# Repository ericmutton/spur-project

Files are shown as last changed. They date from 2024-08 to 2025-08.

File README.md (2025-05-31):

# spur-project

Musings in preparation for the 2025 [Summer Platform for Undergraduate Research](https://spur.utdallas.edu/).

# Getting Started

This repository contains the project files created during my Fall 2024 and Spring 2025 semesters.

## Hardware

The EDA schematic captures and prototype PC boards are maintained in separate KiCAD projects in the [Hardware](/Hardware) directory.
- Single-Cell PMIC and Switch-Mode PSU testbench
- NiceRF SA868 walkie-talkie module breakout board 

## Software

The source code utilizing either the Espressif Systems [ESP-IDF Arduino Core](https://github.com/espressif/arduino-esp32) (using FreeRTOS) for experimentation
or the Zephyr Standalone Application (using ZephyrRTOS) constituting the base radio platform firmware are both maintained in the [Software](/Software) directory.

# Scope

The scope of this research project is to build a two-way radio communications platform that remains extensible in arbitrary 'all-mode' FM modulation in both firmware and hardware.

This means adopting modern real-time operating system ecosystems, particularly the two RTOS under consideration are:
- [Zephyr Project](https://zephyrproject.org) [ZephyrRTOS](https://github.com/zephyrproject-rtos) (a Linux Foundation Project)
- [FreeRTOS](https://freertos.org/) (under Amazon AWS stewardship as of 2017)

For the hardware, the platform is to allow off-the-shelf (and few bespoke) integration of:
 - Wireless communications modules
   - [ ] GNSS/GPS receivers 
   - [ ] Sub-Ghz transceivers
   - [ ] LoRa transceivers
 - Peripheral Human-Machine Interface Devices (HIDs)
   - [ ] Potentiometers (Volume, Frequency), Keypad (DTMF, Navigation), Display
   - [ ] Mono CW Keyer, Keyboard, and USB devices
   - [ ] External audio source/sink, external modem/vocoder

## Groundwork

- [x] Develop a working 'two-way' radio prototype. 
  - [x] Phase out SA868 Demo Board by building a minimal breakout board
  - [x] Make prototype mobile through a rechargable cell and JEITA charger
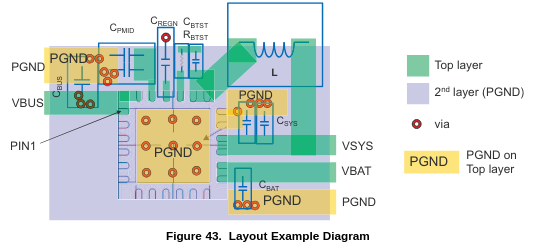
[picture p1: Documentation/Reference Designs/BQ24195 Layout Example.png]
BQ24195
    - 
  - [x] Amplify audio output of SA868 with anything other than an LM386 reference design
  - [x] Allow end-user to enter new RX and TX frequencies
  - [ ] All settings available to the end-user
  - [ ] Persistence of settings between power cycles

## Phase 1

For the purposes here, the SA868 is limited to arbitrary FM modes:
 - Analog FM Voice 
 - Amateur Packet Reporting System (APRS) 
 - Premodulated FM Waveforms

In Analog FM Voice, a parrot test or signal strength report (Readability-Strength-Tone) would be satisfactory.
## Phase 2
After verifying what can be done with the SA868, the next transceiver is the Texas Instruments CC1200. 

## Approach

A first-principles approach in designing this platform is to be taken on:
1. inter-device communications interfacing
   - [x] sensor device register-level configuration
   - [x] factory firmware flashing (see DMO module)
   - [x] microcontroller (a)synchronous peripheral utilization
2. utilizing vendor hardware abstractions
   - [x] device abstraction and tooling
     - [TI SimpleLink SDK](https://www.ti.com/tool/SIMPLELINK-LOWPOWER-SDK) >= v3.3
     - [SmartRF Studio](https://www.ti.com/tool/SMARTRFTM-STUDIO) == v7 (see TI CC1200)
   - [ ] subsystem abstraction
3. utilizing operating system abstractions
   - [ ] target hardware-application decoupling (see ZephyrRTOS)
   - [ ] communications stack normalization (see USB, IEEE 802.15.4, Bluetooth SIG)
   - [ ] tracing & debugging meta-tooling (see [openocd](https://openocd.org/))
4.  extensibility

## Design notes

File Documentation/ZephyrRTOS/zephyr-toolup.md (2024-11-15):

Goal
* Be able to run a driver sample as a [freestanding application](https://docs.zephyrproject.org/latest/develop/application/index.html#zephyr-freestanding-application)
* Run sample for Chargers API with [`ti,bq24190`](https://docs.zephyrproject.org/latest/build/dts/api/bindings/charger/ti,bq24190.html)on i2c `reg = <0x6B>;`

Preconditions
* Review page 17 of [BQ24195 datasheet](https://www.ti.com/lit/ds/symlink/bq24195.pdf)
* Battery charging is enabled by I2C register bit (`REG01[5:4]`) = 01 and CE is low

Methodology
For context, `zephyrproject/zephyr/samples/drivers/charger/src/main.c` has the following DeviceTree device node that needs to be set:
```c
static const struct device *chgdev = DEVICE_DT_GET(DT_NODELABEL(charger));
```

To make a Zephyr freestanding application, a proper zephyr repo instance is accessible but separate from an `app/` directory as shown below:
```md
<home>/
├─── zephyrproject/
│     ├─── .west/
│     │    └─── config
│     ├── zephyr/
│     ├── bootloader/
│     ├── modules/
│     └── ...
│
└─── app/
     ├── CMakeLists.txt
     ├── prj.conf
     ├── boards
         └── esp32c3_devkitm.overlay
     └── src/
         └── main.c
```

The contents of custom device tree overlay overriding `chgdev` for the `boards/esp32c3_devkitm.overlay` with app name `app` is shown below:
```c
&i2c0 {
	status = "okay";
	charger: bq24190@6b {
		compatible = "ti,bq24190";
		reg = <0x6B>; // I2C address of the BQ24195
		constant-charge-current-max-microamp = <2000000>;
		constant-charge-voltage-max-microvolt = <4200000>; 
	};
};
```

```c
cmake_minimum_required(VERSION 3.20.0)

set(BOARD esp32c3_devkitm)

find_package(Zephyr REQUIRED HINTS $ENV{ZEPHYR_BASE})

project(
	BMS-SMPS
	DESCRIPTION "Evaluation project for zephyr,charger API"
	LANGUAGES C
)

target_sources(
	app
	PRIVATE
	src/main.c
)
```

```conf
CONFIG_MAIN_STACK_SIZE=4096

# Enable console support
CONFIG_CONSOLE=y
CONFIG_UART_CONSOLE=y

# Enable GPIO support
CONFIG_GPIO=y

# Enable I2C for the ESP32-C3 Devkit
CONFIG_I2C=y
CONFIG_I2C_INIT_PRIORITY=60
  
# Enable the Charger API
CONFIG_CHARGER=y
# Set up the specific driver
CONFIG_CHARGER_BQ24190=y

# Enable logging (optional, for debugging)
CONFIG_LOG=y
CONFIG_TRACING_SYSCALL=y
CONFIG_LOG_DEFAULT_LEVEL=3
```

Postconditions
* Use an overlay file to set chgdev for using the `zephyr,charger` API sample.
* Put the BQ24193 into `CHARGER_STATUS_CHARGING` to charge an attached single 1.65 V 18650 cell and successfully run the `zephyr,charger` on an ESP32-C3 DEVKITM `--board esp32c3_devkitm`.
* Can run the following commands to build and flash:

```bash
# See https://github.com/zephyrproject-rtos/zephyr/pull/80342/
west init -m https://github.com/rriveramcrus/zephyr
west build
west flash
west espressif monitor
```

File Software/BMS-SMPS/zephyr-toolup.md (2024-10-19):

Goal
* Be able to run a driver sample as a [freestanding application](https://docs.zephyrproject.org/latest/develop/application/index.html#zephyr-freestanding-application)
* Run sample for Chargers API with [`ti,bq24190`](https://docs.zephyrproject.org/latest/build/dts/api/bindings/charger/ti,bq24190.html)on i2c `reg = <0x6B>;`

Preconditions
* Review page 17 of [BQ24193 datasheet](https://www.ti.com/lit/ds/symlink/bq24193.pdf)
* Battery charging is enabled by I2C register bit (`REG01[5:4]`) = 01 and CE is low

Methodology
For context, `zephyrproject/zephyr/samples/drivers/charger/src/main.c` has the following DeviceTree device node that needs to be set:
```c
static const struct device *chgdev = DEVICE_DT_GET(DT_NODELABEL(charger));
```

To make a Zephyr freestanding application, a proper zephyr repo instance is accessible but separate from an `app/` directory as shown below:
```md
<home>/
├─── zephyrproject/
│     ├─── .west/
│     │    └─── config
│     ├── zephyr/
│     ├── bootloader/
│     ├── modules/
│     └── ...
│
└─── BMS-SMPS/
     ├── CMakeLists.txt
     ├── prj.conf
     ├── boards
         └── esp32c3_devkitm.overlay
     └── src/
         └── main.c
```

The contents of custom device tree overlay overriding `chgdev` for the  `boards/esp32c3_devkitm.overlay` with app name `BMS-SMPS` is shown below:
```c
&i2c0 {
	status = "okay";
	charger: bq24190@6b {
		compatible = "ti,bq24190";
		reg = <0x6B>; // I2C address of the BQ24193
		constant-charge-current-max-microamp = <2000000>;
		constant-charge-voltage-max-microvolt = <4200000>; 
	};
};
```

```cmake
cmake_minimum_required(VERSION 3.20.0)

set(BOARD esp32c3_devkitm)

find_package(Zephyr REQUIRED HINTS $ENV{ZEPHYR_BASE})

project(
	BMS-SMPS
	DESCRIPTION "Evaluation project for zephyr,charger API"
	LANGUAGES C
)

target_sources(
	app
	PRIVATE
	src/main.c
)
```

```c
CONFIG_MAIN_STACK_SIZE=4096

# Enable console support
CONFIG_CONSOLE=y
CONFIG_UART_CONSOLE=y

# Enable GPIO support
CONFIG_GPIO=y

# Enable I2C for the ESP32-C3 Devkit
CONFIG_I2C=y
CONFIG_I2C_INIT_PRIORITY=60
  
# Enable the Charger API
CONFIG_CHARGER=y
# Set up the specific driver
CONFIG_CHARGER_BQ24190=y

# # Enable logging (optional, for debugging)
CONFIG_LOG=y
CONFIG_TRACING_SYSCALL=y
CONFIG_LOG_DEFAULT_LEVEL=3
```

Postconditions
* Use an overlay file to set chgdev for using the `zephyr,charger` API sample.
* Put the BQ24193 into `CHARGER_STATUS_CHARGING` to charge an attached single 1.65 V 18650 cell and successfully run the `zephyr,charger` on an ESP32-C3 DEVKITM `--board esp32c3_devkitm`.
* Can run the following commands to build and flash:
```bash
west build
west flash
west espressif monitor
```

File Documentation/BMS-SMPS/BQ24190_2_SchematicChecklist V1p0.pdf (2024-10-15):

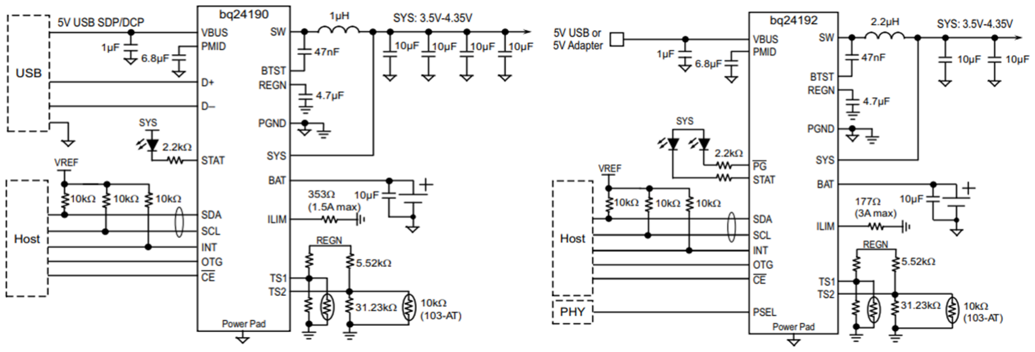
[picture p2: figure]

PIN NAME | REQUIREMENT | COMPONENT | MIN | TYP | MAX | DESCRIPTION | COMMENTS AND RELEVANT EQUATIONS
D+/D‐ BQ24190 ONLY | 2,3 | | USB data line pair
Optional | | | | | Positive line of the USB data line pair. | 1. D+/D‐ based USB host/charging port detection. The detection includes data contact detection(DCD), primary and secondary detection in BC1.2.
Optional | | | | | Negative line of the USB data line pair. | 2. If D+/D‐ based input current limit detection is not used, short D+/D‐ pins together.
PSEL BQ24192 ONLY | 2 | | Power source selection input.
Required | | | | | | High indicates a USB host source and Low indicates an adapter source. Do not float.
/PG BQ24192 ONLY | 3 | | Open drain active low power good indicator.
Optional | PG resistor | | 2.2 kΩ | 10 kΩ | Connect to the pull up rail via 10‐kΩ resistor. | LOW indicates a good input source if the input voltage is between UVLO and ACOV, above SLEEP mode threshold, and current limit is above 30 mA.
STAT | 4 | | Open drain charge status output
Optional | STAT resistor | | 2.2 kΩ | 10 kΩ | Connect to the pull up rail via 2.2‐kΩ resistor. | 1. If not used, leave it float. 2. HIGH indicates charge complete or charge disabled. When any fault Digital condition occurs, STAT pin in blinks at 1 Hz.
SCL/SDA | 5‐6 | | I2C Interface clock and data
Optional | SCL resistor | | 10 kΩ | | Connect SCL to the logic rail through a 10‐kΩ resistor. | If I2C communication is not used, leave it float.
Optional | SDA resistor | | 10 kΩ | | Connect SDA to the logic rail through a 10‐kΩ resistor. | If I2C communication is not used, leave it float.
INT | 7 | | Open‐drain Interrupt Output
Optional | INT resistor | | 10 kΩ | | Connect the INT to a logic rail via 10‐kΩ resistor. | 1. If not used, leave it float. 2. The INT pin sends active low, 256‐μs pulse to host to report charger device status and fault.
OTG | 8 | | Active high enable pin during boost mode.
Optional | | | | | USB current limit selection pin during buck mode, and active high enable pin during boost mode. | 1. If OTG boost mode is not used, short it to ground. 2. In buck mode with USB host (PSEL=High), when OTG = High, IIN limit = 500 mA and when OTG = Low, IIN Digital limit = 100 mA. 3. The boost mode is activated when the REG01[5:4] = 10 and OTG pin is High.
/CE | 9 | | Active low Charge Enable pin.
Required | | | | | | 1. /CE pin must be pulled High or Low. 2. Battery charging is enabled when REG01[5:4] = 01 and CE pin = Low.
ILIM | 10 | | Input current limit Input.
Required | ILIM resistor | | * Ω | | A resistor is connected from ILIM pin to ground to set the maximum limit as IINMAX = (1V/RILIM) × 530 | 1. The actual input current limit is the lower one set by ILIM and by I2C REG00[2:0]. 2.The minimum input current programmed on ILIM pin is 500 mA. 3. If ILIM pin is short, the input current limit is set by the register. 4. If ILIM pin is open, the input current is limited to zero
TS1, TS2 | 11,12 | | Temperature qualification voltage inputs.
Required | TS resistors and thermistor | | | | Connect a negative temperature coefficient thermistors. Recommend 103AT‐2 thermistors. | 1. If thermistor is not used, set TS pin voltage within normal range. 2. If thermistor is used, program temperature window with a resistor divider from REGN to TSx to GND. Charge suspends when either TS pin is out of range.
VBUS | 1,24 | | Input source to the charger
Required | VBUS caps | 1uF | | | | 1. Place a 1‐μF ceramic capacitor from VBUS to PGND and place it as close as possible to IC. 2. It is recommended to have a total of ~10uF capacitance at VBUS & PMID for USB input compliance.
PMID | 23 | | Actual input source to the charger
Required | PMID caps | 6.8uF | | | | Given the total input capacitance, put 1 μF on VBUS to PGND, and the rest capacitance on PMID to PGND.
VBAT | 13‐14 | | Positive battery connection point
Required | VBAT caps | 10uF | 10uF | | | 1. Connect a 10 μF closely to the BAT pin. 2. Charger may operate normally when battery is not connected.
VSYS | 15‐16 | | System connection point.
Required | VSYS caps | 20uF | 20uF | 40uF | | Connect a 20 μF closely to the SYS pin. The preferred ceramic capacitor is 6V or higher rating, X7R or X5R.
SW | 19‐20 | | Switching node connecting to output inductor.
Required | Output inductor | 1uH | | 2.2uH | | The charger device has internal loop compensator. To get good loop stability, the resonant frequency of the output inductor and output capacitor should be designed between 15 kHz and 25 kHz. With 2.2‐μH inductor, the typical output capacitor value is 20 μF.
| | Optional | SW Resistor | | * Ω | | Switching converter snubber circuit | Snubber circuit values empirically determined if required. Recommend unpopulated footprint on new designs.
| | Optional | SW Cap | | * F
BTST | 21 | | | | | | PWM high side driver positive supply.
| | Required | BTST‐SW cap | 0.047uF | 0.047uF | 0.047uF | | Connect the 0.047μF bootstrap capacitor from SW to BTST.
| | Optional | BTST resistor | | * Ω | | Bootstrap capacitor snubbing resistor | Help with EMI performance. Recommend unpopulated footprint on new designs.
REGN | 22 | | | | | | PWM low side driver positive supply output.
| | Required | REGN cap | 4.7uF | 4.7uF | 4.7uF | | Connect a 4.7 μF (10 Vrating) ceramic capacitor from REGN to analog GND. The capacitor should be placed close to the IC. REGN also serves as bias rail of TS1 and TS2 pins.
PGND | 17‐18 | | | | | | Power ground connection for high‐current power converter node.
| | Required | | | | | | On PCB layout, connect directly to ground connection of input and output capacitors of the charger. A single point connection is recommended between power PGND and the analog GND near the IC PGND pin.
PowerPAD | | Required | | | | | | Always solder PowerPAD Pad to the board, and have vias on the PowerPAD plane star‐connecting to PGND and ground plane for high‐current power converter.

## BQ24190/2 TYPICAL SCHEMATIC

## BQ24190/2 SCHMATIC CHECKLIST

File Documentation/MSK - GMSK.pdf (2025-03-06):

Appendix D – University of Hull | D1

### Appendix D – Digital Modulation and GMSK

A brief introduction to digital modulation schemes is given, showing the logical development of GMSK from simpler schemes. GMSK is of interest since it is used in the GSM system. The phase and amplitude relations between carrier cycles over a data bit are developed, enabling rigourous modelling of ensemble fields to be carried out.

D1. Phase shift keying

For binary PSK (BPSK)

S0(t) = A cos (ωt) | represents binary “0”
S1(t) = A cos (ωt + π) | represents binary “1”

For M-ary PSK, M different phases are required, and every n (where M=2n ) bits of the
binary bit stream are coded as one signal that is transmitted as
A sin (ωt + θj)
j=1,...,M.

D2. Quadrature Phase Shift Keying

If we define four signals, each with a phase shift differing by 90⁰
then we have
quadrature phase shift keying (QPSK).

The input binary bit stream {dk}, dk = 0,1,2,..... arrives at the modulator input at a rate 1/T bits/sec and is separated into two data streams dI (t) and dQ (t) containing odd and even bits respectively.
dI(t) = d0, d2, d4 ,...
dQ(t) = d1, d3, d5 , ...

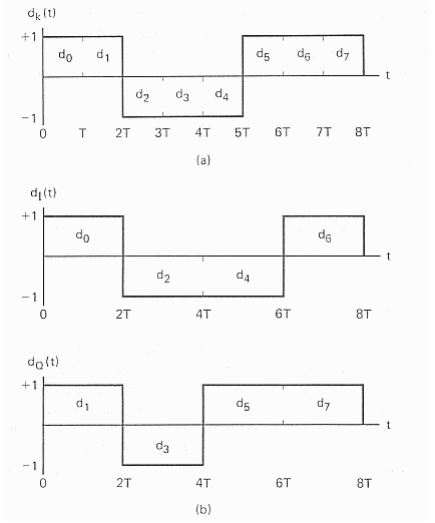
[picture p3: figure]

A convenient orthogonal realisation of a QPSK waveform , s(t) is achieved by amplitude modulating the in-phase and quadrature data
streams onto the cosine and sine functions of a carrier wave as follows:

s(t)=1/ 2 dI(t) cos (2πft + π/4) + 1/ 2 dQ(t) sin (2πft + π/4)

Using trigonometric identities this can also be written as

s(t)=A cos [2πft + π/4 + θ(t)].

The pulse stream dI(t) modulates the cosine function with an amplitude of ± 1. This is equivalent to shifting the phase of the cosine function by 0 or π; consequently this produces a BPSK waveform. Similarly the pulse stream dQ(t) modulates the sine function, yielding a BPSK waveform orthogonal to the cosine function. The summation of these two orthogonal waveforms is the QPSK waveform.

The values of θ(t) = 0, -(π/2), π/2, π represent the four possible combinations of aI (t) and aQ (t).

Each of the four possible phases of carriers represents two bits of data. Thus there are two bits per symbol. Since the symbol rate for QPSK is half the bit rate, twice as much data can be carried in the same amount of channel bandwidth as compared to BPSK. This is possible because the two signals I and Q are orthogonal to each other and can be transmitted without interfering with each other.

In QPSK the carrier phase can change only once every 2T secs. If from one T interval to the next one, neither bit stream changes sign, the carrier phase remains unchanged. If one component aI(t) or aQ (t) changes sign, a phase change of π/2 occurs. However if both components change sign then a phase shift of π occurs.

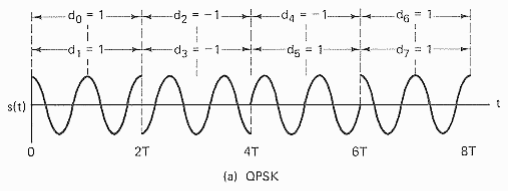
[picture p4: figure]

If a QPSK modulated signal undergoes filtering to reduce the spectral side lobes, the resulting waveform will no longer have a constant envelop and in fact, the occasional 180o
shifts in phase will cause the envelope to go to zero momentarily.

D3. Offset Quadrature Phase Shift Keying

If the two bit streams I and Q are offset by a 1/2 bit interval, then the amplitude fluctuations are minimised since the phase never changes by 180o
. This modulation
scheme, Offset Quadrature Phase shift Keying (OQPSK) is obtained from QPSK by delaying the odd bit stream by half a bit interval with respect to the even bit stream.

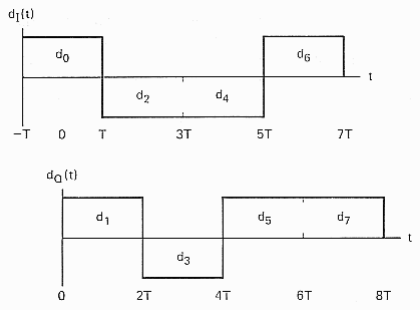
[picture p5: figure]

Thus the range of phase transitions is 0o

and 90o
(the possibility of a phase shift of 180o
is eliminated) and occurs twice as often, but with half the intensity of the QPSK. While amplitude fluctuations still occur in the transmitter and receiver they have smaller magnitude. The bit error rate for QPSK and OQPSK are the same as for BPSK.

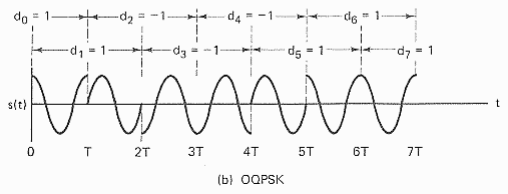
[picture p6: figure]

When an OQPSK signal undergoes bandlimiting, the resulting intersymbol interference causes the envelop to droop slightly to the region of ± 90o
phase transition, but since the phase transitions of 180 have been avoided in OQPSK, the envelop will never go to zero as it does in QPSK.

D4. Minimum Shift Keying

We previously showed that OQPSK is obtained from QPSK by delaying the Q data stream by 1 bit or T seconds with respect to the I data stream. This delay has no effect on the error or bandwidth.

Minimum Shift Keying (MSK) is derived from OQPSK by replacing the rectangular pulse in amplitude with a half-cycle sinusoidal pulse. The MSK signal is defined as:

S(t) = d(t) cos (πt/2T) cos 2πft + d(t) sin (πt/2T) sin 2πft.

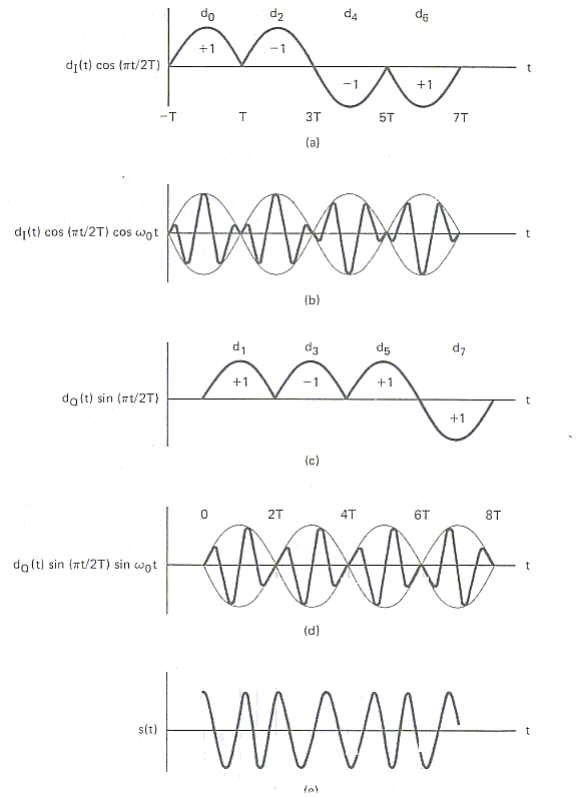
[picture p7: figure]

The MSK modulation makes the phase change linear and limited to ± (π/2) over a bit interval T. This enables MSK to provide a significant improvement over QPSK. Because of the effect of the linear phase change, the power spectral density has low side lobes that help to control adjacent-channel interference. However the main lobe becomes wider than the quadrature shift keying.

D5. Gausssian Minimum Shift Keying (GMSK)

In MSK we replace the rectangular pulse with a sinusoidal pulse. Obviously other pulse shapes are possible. A Gaussian-shaped impulse response filter generates a signal with low side lobes and narrower main lobe than the rectangular pulse. Since the filter theoretically has output before input, it can only be approximated by a delayed and shaped impulse response that has a Gaussian - like shape. This modulation is called Gaussian Minimum Shift Keying (GMSK).

The relationship between the premodulation filter bandwidth, B and the bit period, T defines the bandwidth of the system. GSM designers used a BT = 0.3 with a channel data rate of 270.8 kbs. This compromises between a bit error rate and an out-of-band interference since the narrow filter increases the intersymbol interference and reduces the signal power.

D5.1 GMSK Modulation
There are two methods to generate GMSK, one is frequency shift keyed modulation, the other is quadrature phase shift keyed modulation.

GMSK implemented by Frequency Shift Keying modulation with FM-VCO.

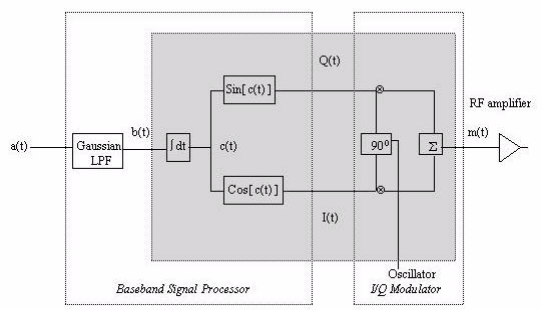
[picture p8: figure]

GMSK implemented by a quadrature baseband method.

The shaded areas in the two above figures have the same function.

The GMSK VCO-modulator architecture as shown in the first is simple but is not however, suitable for coherent demodulation due to component tolerance problems. This method requires that the frequency deviation factor of the VCO exactly equals 0.5, but the modulation index of conventional VCO based transmitters drifts over time and temperature.

a(t)

m(t) | RF Amplifier Gaussian
LPF

VCO
m=0.5

The implementation in the second employs a quadrature baseband process followed by a quadrature modulator. With this implementation, the modulation index can be maintained at exactly 0.5. This method is also cheaper to implement.

Both methods lead to the same GMSK modulated signal.

We are going to be looking at the second of these two methods, that is we shall be looking at a quadrature baseband processor followed by a quadrature modulator as shown in the second.

The Gaussian low-pass filter has an impulse response given by the following equation

g(t) = 1
2T [Q(2πBb

t − T /
ln

2
2 )-Q(2πBb

t + T /
ln

2
2 )]

for

0≤ Bb T ≤ ∞
where Q(t) is the Q-function

Q(t) = 1
2 t

∫ exp (-x²
/2) dx ,

Bb is the bandwidth of the low pass filter having a Gaussian shaped spectrum, T is the bit period and BN=Bb T is the normalised bandwidth.

To demonstrate this, we are looking at a filter with a bandwidth of Bb =1000 and a bit rate of T=1/2000, i.e. a normalised bandwidth BN=Bb.T =0.5.

The impulse response of the Gaussian low-pass filter has to be truncated and scaled, according to the BN value, to ensure that the effect of a single 1 passing through the filter, is a phases change of π/2.

For a BN of 0.5 the filter response is truncated, symmetrically around zero, to two bit periods, i.e. from -T to T. The truncated filter response is represented graphically in the following figure.

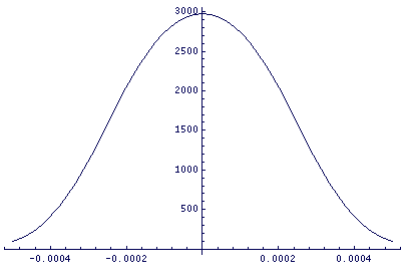
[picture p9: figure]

Ensuring that the response of the filter to a single 1 is a phase change of π/2, is equivalent to choosing the constant K to satisfy the following equation

Kg t dt

T

T
( ) =

−

∫ | π/2.

To demonstrate the modulation, we are using the following randomly chosen binary data stream. (This data stream repeats after 12 bits.)

{1,1,-1,1,1,-1,-1,1,-1,1,-1,-1, 1,1,-1,1,1,-1,-1,1,-1,1,-1,-1, | }.

The beginning of this data stream can be represented graphically by the following

The truncated and scaled impulse response of the Gaussian low-pass filter.

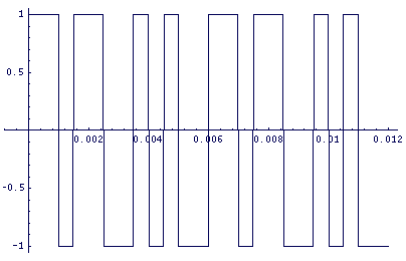
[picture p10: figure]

The beginning of the data stream being sent through the filter.

As the data passes through the filter it is shaped and ISI (inter symbol interference) is introduced since more than one bit is passing through the filter at any one time. For BN = 0.5, since the bits are spread over two bit periods, the second bit enters the filter as the first is half way through, the third enters as the first leaves etc....

The first few Gaussian shaped pulses are represented graphically in the following figure.

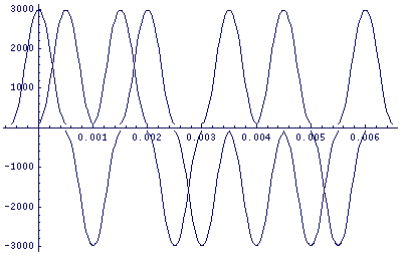
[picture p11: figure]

These individual shaped pulses are then added together to give a function which is represented graphically in the following figure. This is the function denoted by b(t).

The individual shaped pulses representing the data stream.

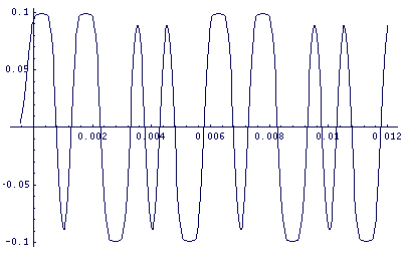
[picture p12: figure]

The function b(t) as in the second figure

This function, b(t), is then integrated, with respect to t (time) from t to ∞, to give the function c(t) as shown in the second figure. This function c(t) is represented graphically below.

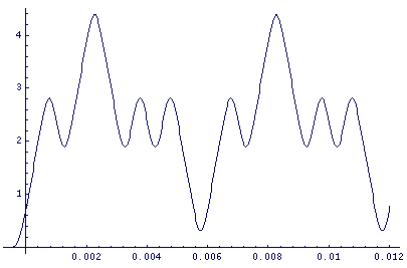
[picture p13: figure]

Once we have the function c(t), we take Sine and Cosine functions of it to produce the I and Q-baseband signals. Taking the Cosine of c(t) produces the I-baseband signal I(t) i.e.

I(t) = Cos[ c(t) ].

This function I(t) is represented graphically below.

The function c(t) as in the second figure.

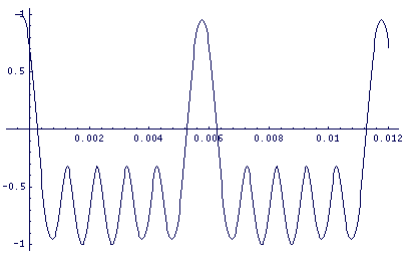
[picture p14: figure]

The I-baseband signal, i.e. the function I(t) as the second figure

Taking the Sine of c(t) produces the Q-baseband signal Q(t) i.e.

Q(t) = Sin[ c(t) ].

This function Q(t) is represented graphically below.

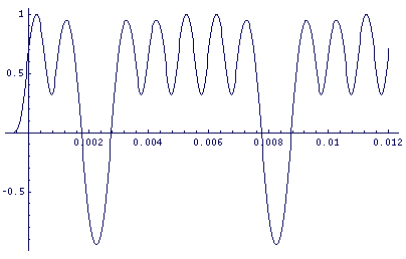
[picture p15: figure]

These two functions I(t) and Q(t) are then passed through the I/Q modulator which leads to the output signal m(t) which can be written as

m(t) = Sin(2πfc t) I(t) + Cos(2πfct) Q(t),

where fc is the carrier frequency used as the oscillator in the second figure

The GMSK signal m(t) is represented

The Q-baseband signal, i.e. the function Q(t) as in the second figure.

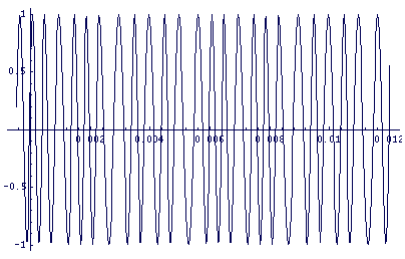
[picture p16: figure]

The GMSK modulated signal m(t) as in the second figure.

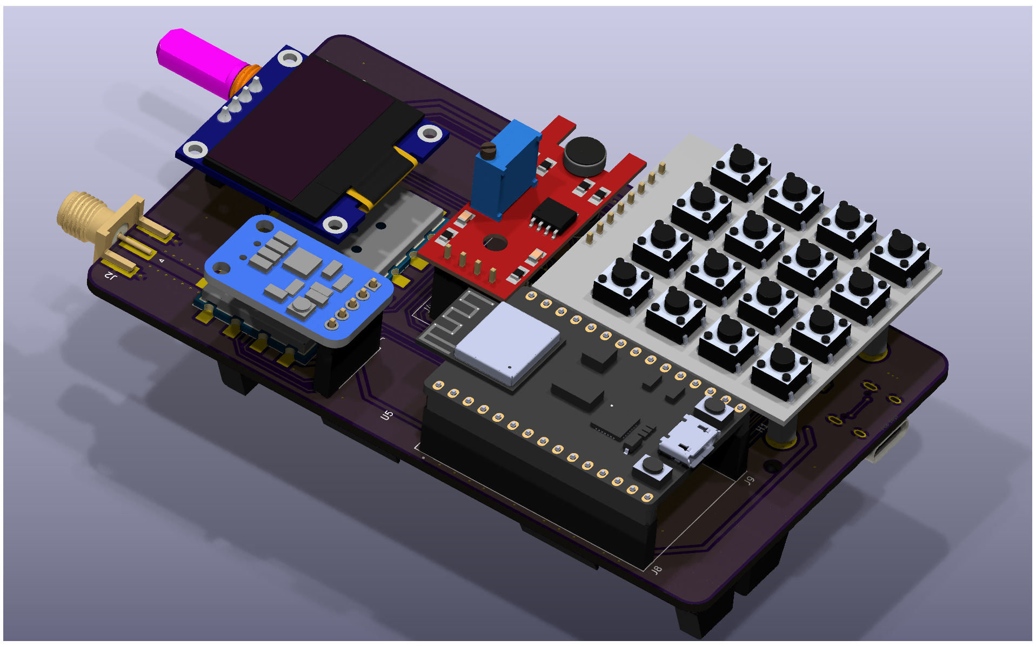
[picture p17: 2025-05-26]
Hardware/KiCAD/spur-demo/spur-demo.png

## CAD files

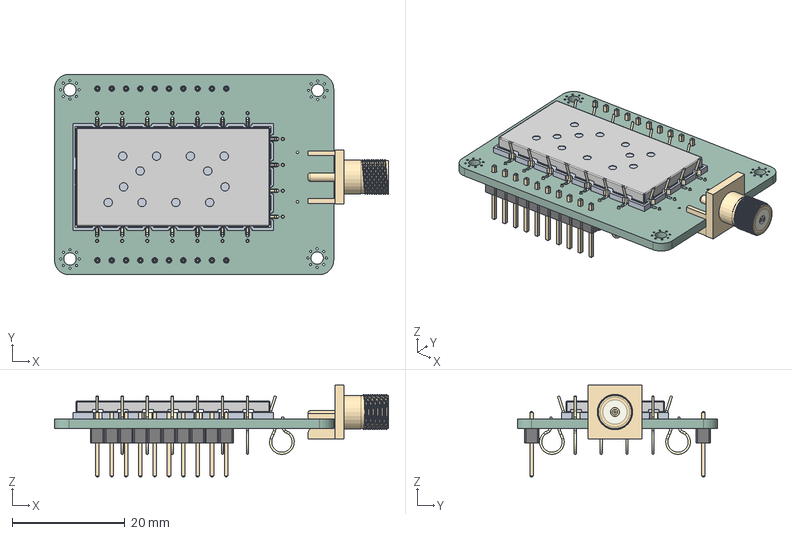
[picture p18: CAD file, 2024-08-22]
Hardware/KiCAD/sa8x8-breakout/sa8x8-breakout.step
59.3 x 35.6 x 16.2 mm
(Unsaved) x 18
SMA_Molex_73251-1153_EdgeMount_Horizontal
SA818 v44
PinHeader_1x10_P254mm_Vertical x 2
sa8x8-breakout_PCB

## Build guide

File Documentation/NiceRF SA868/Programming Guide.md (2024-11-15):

# Programming Guide

##  Flashing the SA868 RF Module

If using the SA868 OpenEdition, it is necessary to flash a firmware onto the onboard Renesas RL78 microcontroller. The requisite programming interface is exposed on the module as shown below.

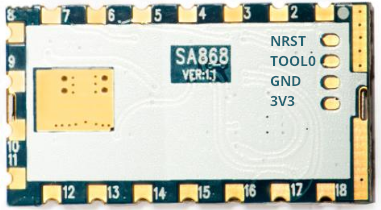
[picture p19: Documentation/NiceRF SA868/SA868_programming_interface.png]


> [!IMPORTANT] 
> The [rl78flash](https://github.com/msalau/rl78flash) command line serial programmer is required for these steps.

To flash the module, mode 3 is specified for the serial bootloader. a USB-TTY serial programming cable must then be fashioned to reflect the requisite hardware as shown below.

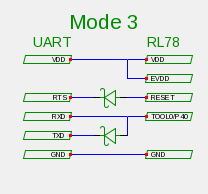
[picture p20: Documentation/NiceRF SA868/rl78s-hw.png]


```bash
rl78flash -m 3 -a -v /dev/ttyUSB0 sa868s-v1.0-patched.s37
```

## Communicating with the SA868

### Factory SA868 communication protocol

#### UART Interface Configuration
* Baud rate = 9600 Baud
* Data bit = 8 bit
* Parity = None
* Stop bit = 1 bit
* Logic Levels = 0 V, 3.3 V

#### Instruction Transmission Format

* `AT+DMOCONNECT`
* `S+sweep_freq`
    - `[134:174]`.[mod 1250]: valid VHF frequency when BW = `0`
    - `[400:480]`.[mod 2500]: valid UHF frequency when BW = `1`
* `AT+DMOSETGROUP=bandwidth_wide_fm,tx_freq,rx_freq,tx_subaudio,squelch,rx_subaudio`
    - bandwidth_wide_fm `[0:1]`: `0` = 12.5kHz or `1` = 25kHz
    - tx_freq, rx_freq
        - `[134:174].[mod 1250]`: valid VHF frequency when BW = `0`
        - `[400:480].[mod 2500]`: valid UHF frequency when BW = `1`
    - tx_subaudio, rx_subaudio
        - `0000`: subaudio disabled 
        - `[0001:0038]`: CTCSS
        - `[023?:754?]`: CDCSS code (?=N indicates complement or ?=I)
    - squelch `[0:8]`: `0` = listen mode or `[1:8]` squelch
* `AT+DMOSETVOLUME=volume_level`
    - `[1:8]`: set configured volume level to X
* `AT+RSSI?`
* `AT+SETFILTER=emphasis,voice_highpass,voice_lowpass`
    - `0`: emphasis,voice_highpass,voice_lowpass normal
    - `1`: emphasis,voice_highpass,voice_lowpass bypass

#### Instruction Return Format:

* `+DMOCONNECT:0` -> Normal working status
* `S=X`
  - `S=0` -> The frequency to be scanned has a signal
  - `S=1` -> There is no signal to sweep the frequency
* `+DMOSETGROUP=X`
  - `+DMOSETGROUP:0` -> Successfully set working parameters
  - `+DMOSETGROUP:1` -> Data setting is out of range
* `DMOSETVOLUME=X`
  - `+DMOSETVOLUME:0` -> Successfully set volume level
  - `+DMOSETVOLUME:1` -> Failed volume level setup
* `RSSI:XXX` -> Current signal strength value from 0 to 255, unit 1dB
* `+DMOSETFILTER:X`
  - `+DMOSETFILTER:0` -> Successfully set module filter
  - `+DMOSETFILTER:1` -> Failed filter setup

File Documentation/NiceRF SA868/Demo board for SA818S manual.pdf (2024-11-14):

# SA818 MANUAL

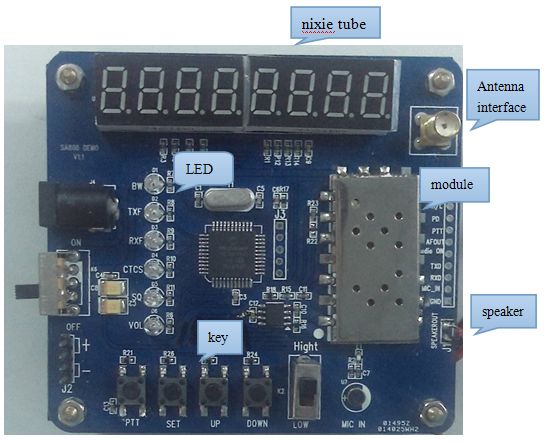
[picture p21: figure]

Key operation:
1 key SET
Press it to setting mode, the data on LED nixie tube will be flickering, you can change it by key UP or DOWN; Press key SET again, the item flickering will shift. If the item flickering is the last one, it will quit setting mode.

2 key UP
When in setting mode, pressing key UP will increase the flickering value.

3 key DOWN
When in setting mode, pressing key DOWN will decrease the flickering value. Otherwise it will move down the light LED.

4 key PTT
Pressing it will make the module into sending mode, when loosen the module into receiving mode.

5 Dial switch
When sending mode, switch to HIGH will send with high power, switch to LOW will send with low power.

Set TX frequency
After power on, the LED close to “TXF” is on, indicates that LED nixie tube is displaying TX frequency. Press key SET, the highest order of frequency will flicker, and can be changed by key UP or

DOWN. Press key SET to set the next order.

Set bandwidth
Press key DOWN, the LED close to “BW” is on, indicates that LED nixie tube is displaying bandwidth, pressing key SET to setting mode and press key DOWN to change bandwidth.

Set RX subaudio.
Press key DOWN, the two LEDS close to “RXF” and “CTCS” are light up, it indicates that LED nixie tube is displaying receiving subaudio. Press key SET to change receiving subaudio. If the LED nixie tube display “00”, it means that no subaudio in receiving mode. If display “tcs”, it means that receiving subaudio is analog, and if display “cds”, it means that receiving subaudio is digital.

Set volume
Press key DOWN, the LED close to “VOL” is on, press key SET to setting mode, and can be changed by key UP or DOWN.

Set SQ
Press key DOWN, the LED close to “SQ” is on, press key SET to setting mode, and can be changed by key UP or DOWN.

Set TX subaudio.
Press key DOWN, the two LEDS close “TXF” and “CTCS” are on, indicates that LED nixie tube is displaying sending subaudio. Press key SET to change sending subaudio. If the LED nixie tube display “00”, it means that no subaudio in sending mode. If display “tcs”, it means that sending subaudio is analog, and if display “cds”, it means that sending subaudio is digital.

Set RX frequency
Press key DOWN, the LED close to “RXF” is on, indicates that LED nixie tube is displaying RX frequency. Press key SET, the highest order of frequency will flickering, and can be changed by key UP or DOWN.

Press key SET to set the next order.
Press key UP, it will start to scan frequency and subaudio, the frequency displayed on the LED nixie tube will increase quickly and check the module whether receive the frequency and the subaudio, it will stop when there is any signal or press key DOWN.

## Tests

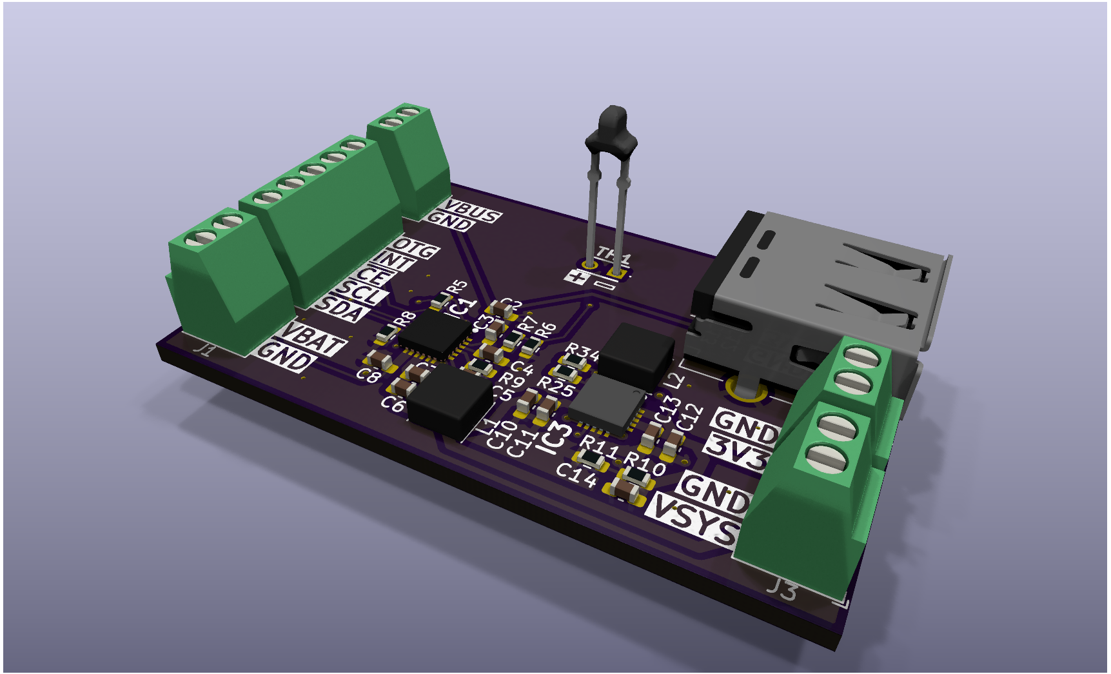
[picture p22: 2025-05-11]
Hardware/KiCAD/bms-smps-testbench/image.png

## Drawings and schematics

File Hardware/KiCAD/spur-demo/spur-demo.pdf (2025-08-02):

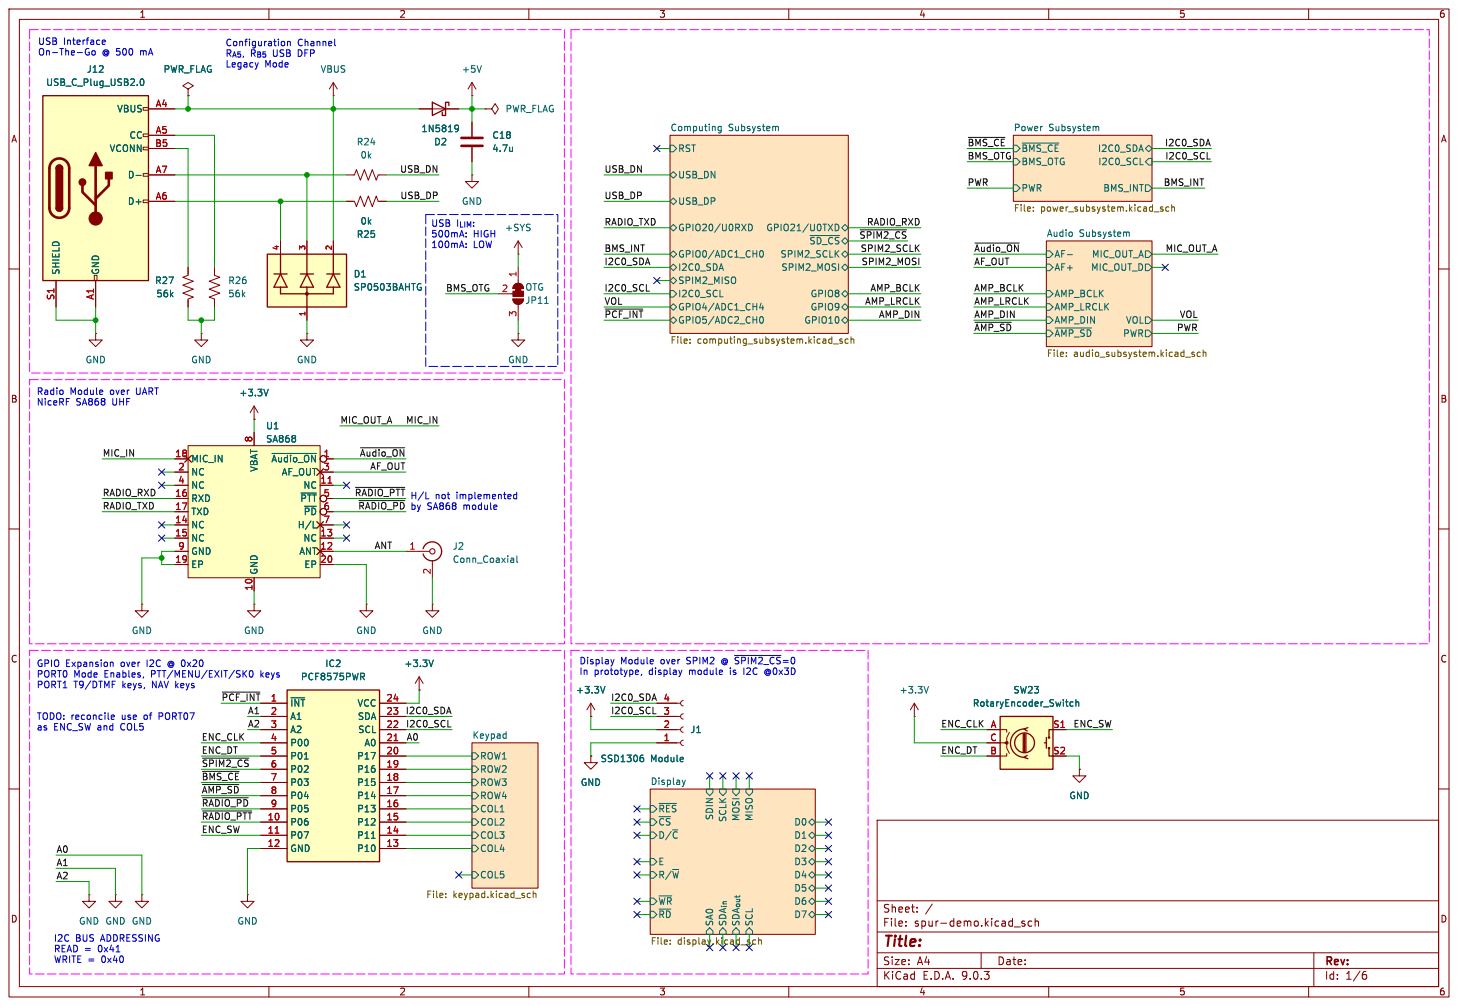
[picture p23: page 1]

Id: 1/6 Title: File: spur-demo.kicad_sch Sheet: /

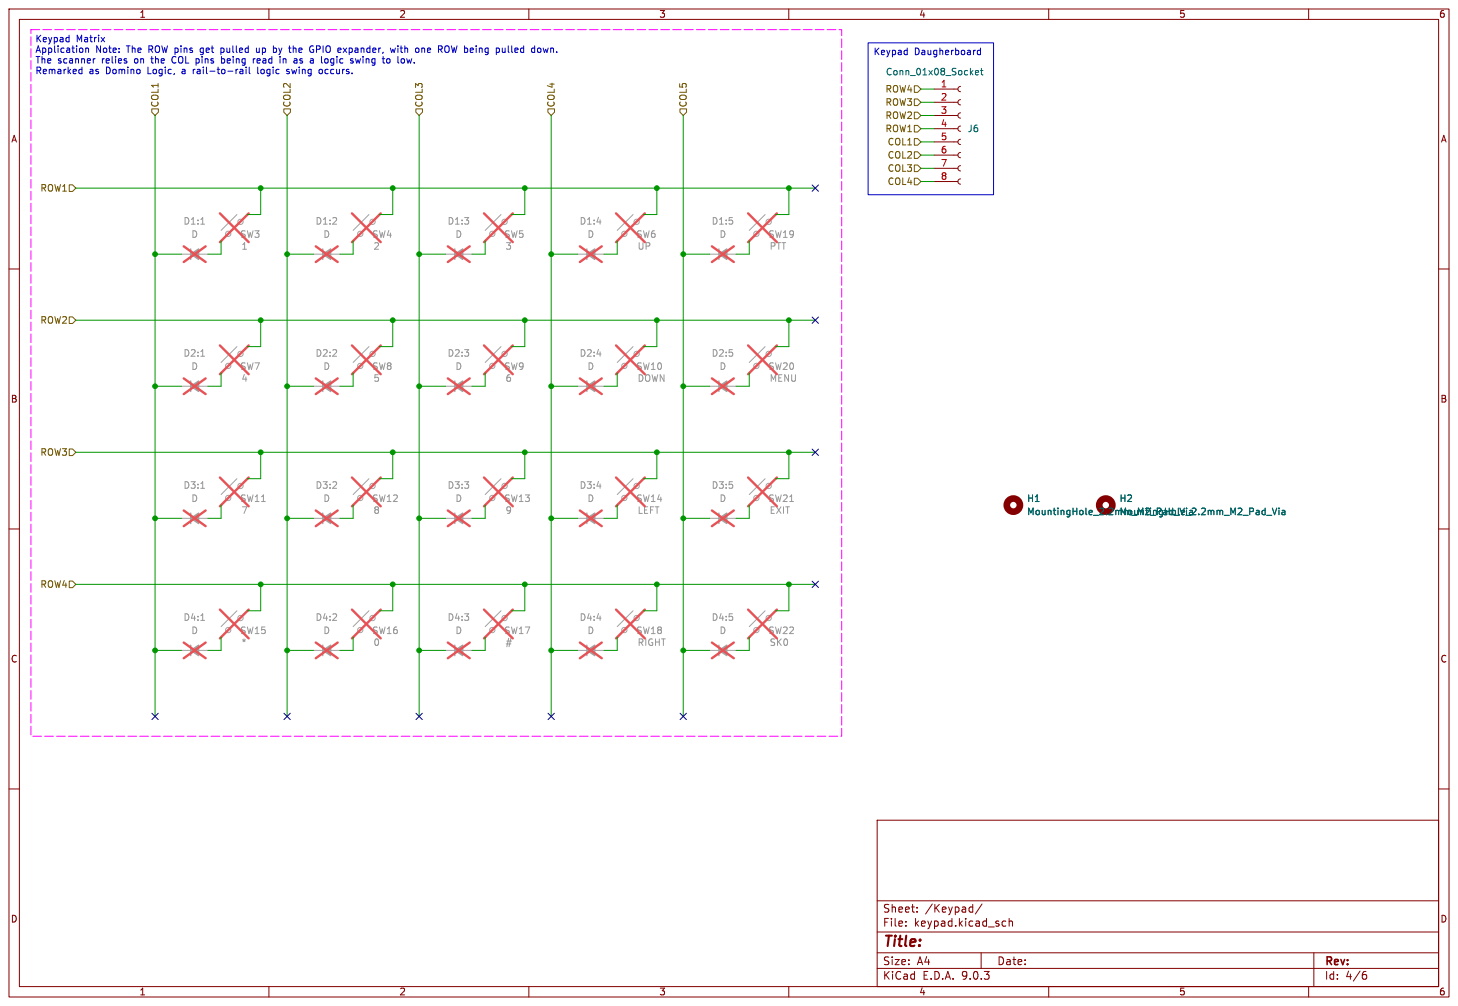
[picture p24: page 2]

Id: 4/6 Title: File: keypad.kicad_sch Sheet: /Keypad/

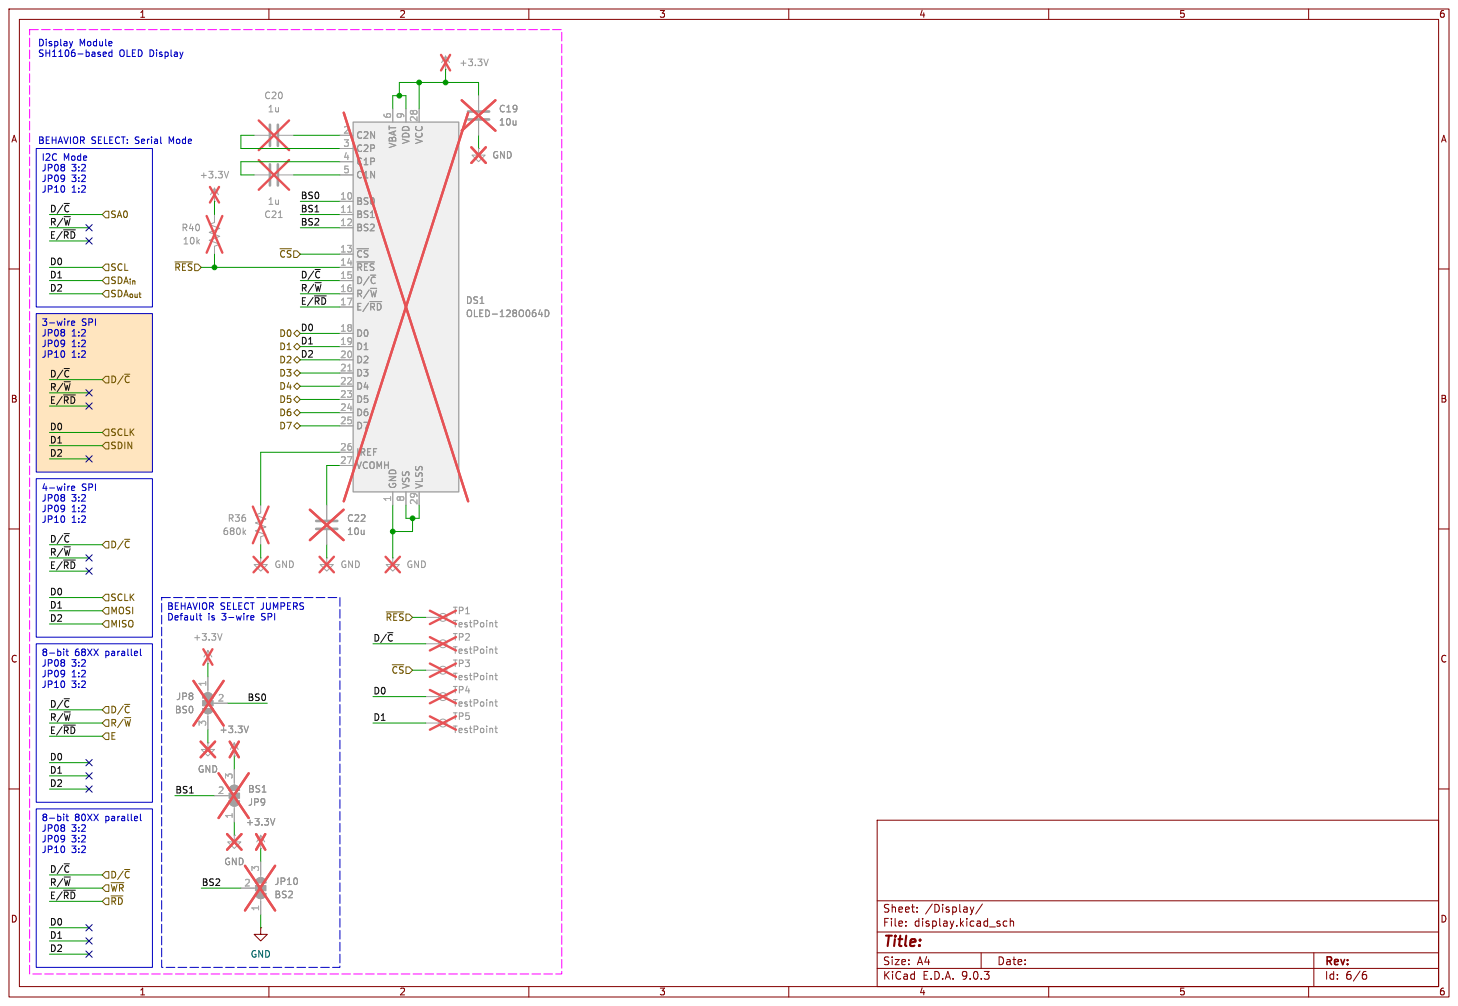
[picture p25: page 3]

Id: 6/6 Title: File: display.kicad_sch Sheet: /Display/

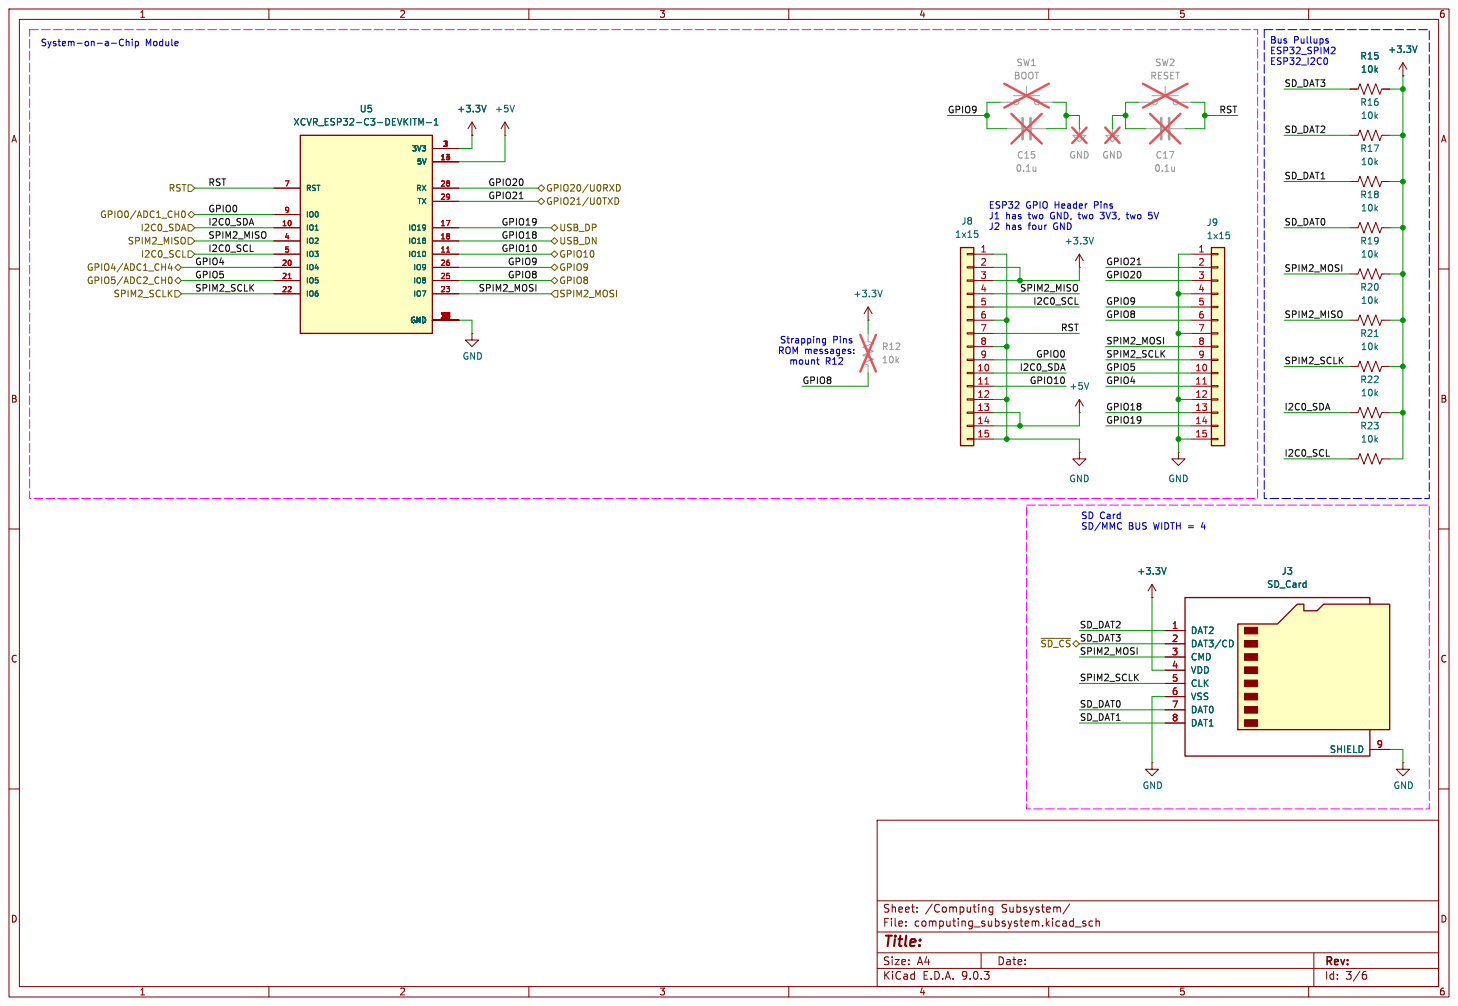
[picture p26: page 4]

J1 has two GND, two 3V3, two 5V
J2 has four GND

SD Card SD/MMC BUS WIDTH = 4

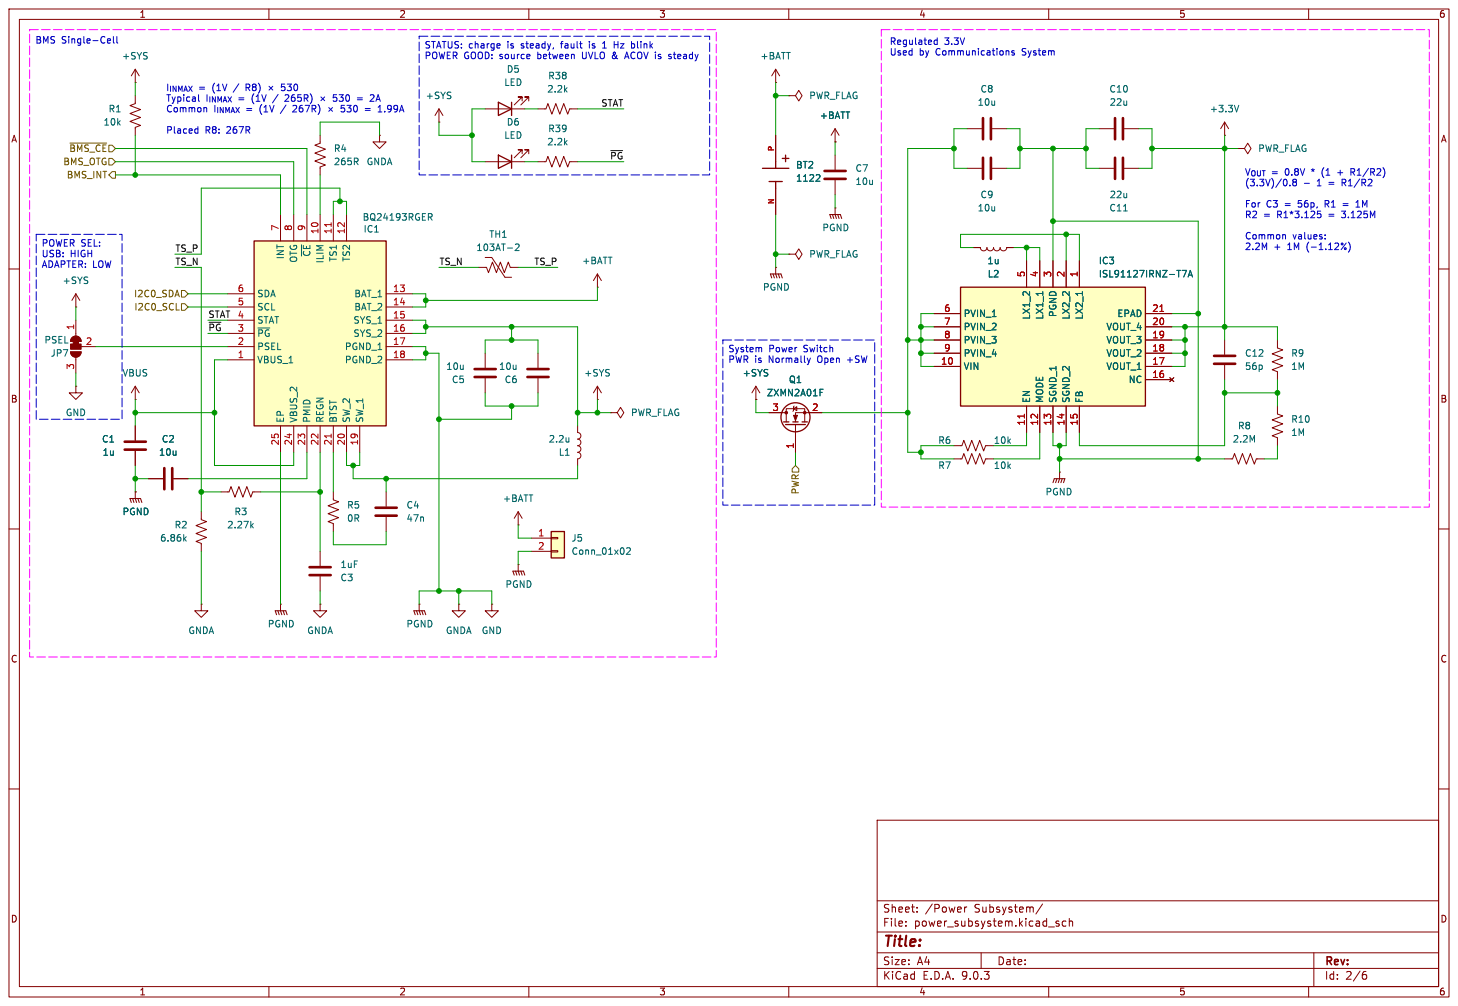
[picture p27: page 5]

STATUS: charge is steady, fault is 1 Hz blink POWER GOOD: source between UVLO & ACOV is steady
LED

I_{INMAX} = (1V / R8) þÿ×530 Typical I_{INMAX} = (1V / 265R) þÿ×530 = 2A Common I_{INMAX} = (1V / 267R) þÿ×530 = 1.99A

5 EPAD 21 PVIN_1 6 VOUT_4 20 PVIN_2 7 VOUT_3 19 PVIN_3 8 VOUT_2 18 PVIN_4 9 VOUT_1 17 VIN 10 NC 16 FB 15 SGND_2 14 SGND_1 13 MODE 12 EN 11 BT2
1122PWR_FLAG

8 PMID 23 ~{CE} 9 REGN 22 ILIM 10 BTST 21 TS1 11 SW_2 20 TS2 12 SW_1 19 PGND_2 18 PGND_1 17 SYS_2 16 SYS_1 15 BAT_2 14 BAT_1 13

POWER SEL: USB: HIGH
+SYS GND

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

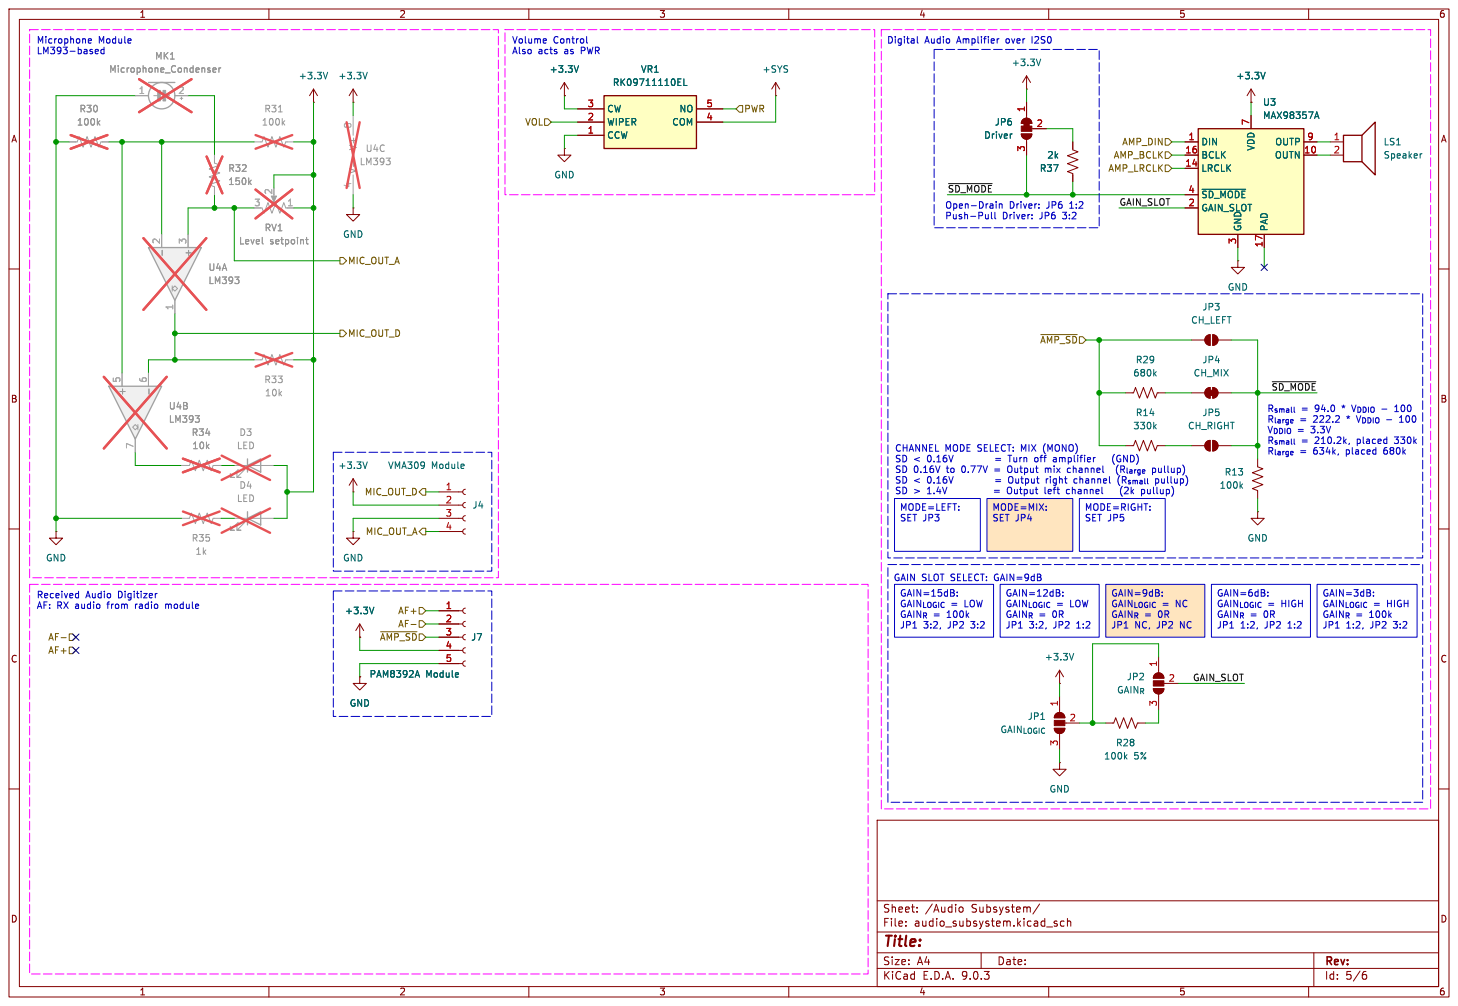
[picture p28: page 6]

R_{small}= 94.0 * V_{DDIO} - 100 R_{large}= 222.2 * V_{DDIO} - 100 V_{DDIO} = 3.3V R_{small}= 210.2k, placed 330k R_{large}= 634k, placed 680k R30

JP1 1:2, JP2 1:2 MODE=MIX: SET JP4 GAIN=12dB: GAIN_{LOGIC} = LOW

JP1 1:2, JP2 3:2 MODE=RIGHT: SET JP5 GAIN=9dB: GAIN_{LOGIC} = NC GAIN_{R}= 0R

Received Audio Digitizer AF: RX audio from radio module

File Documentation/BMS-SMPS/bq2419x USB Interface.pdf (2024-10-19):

# bq24190 Interface to USB

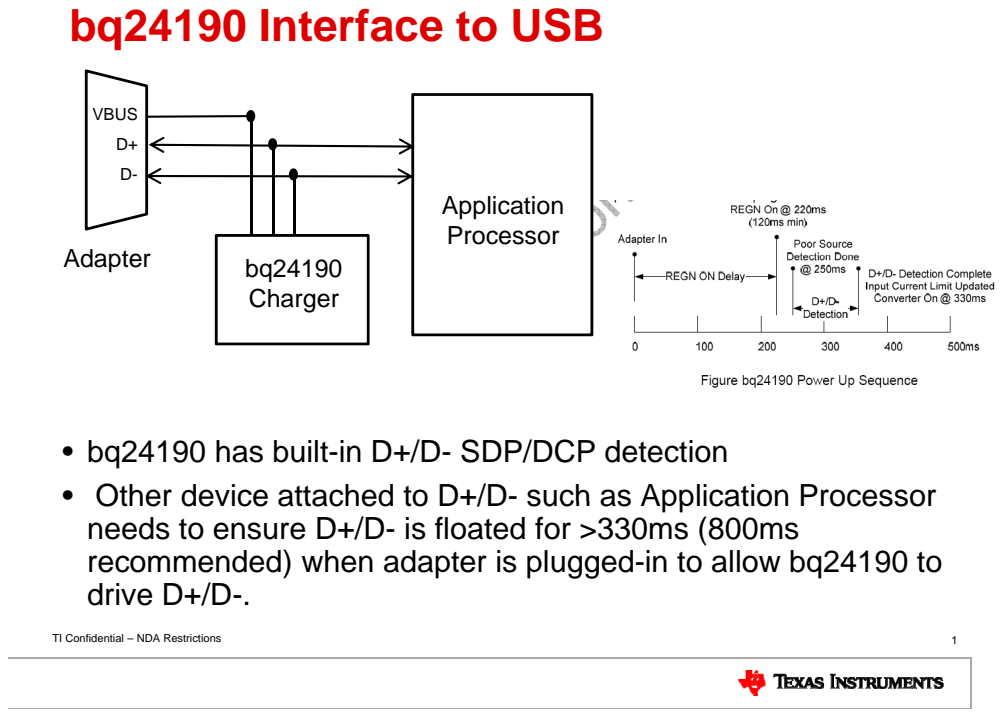
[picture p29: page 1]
VBUS; Application Processor; bq24190 Adapter Charge; TI Confidential – NDA Restrictions

• bq24190 has built-in D+/D- SDP/DCP detection
• Other device attached to D+/D
needs to ensure D+/D- is floated for >330ms (800ms
recommended) when adapter is plugged-in to allow bq24190 to
drive D+/D-.

- such as Application Processor

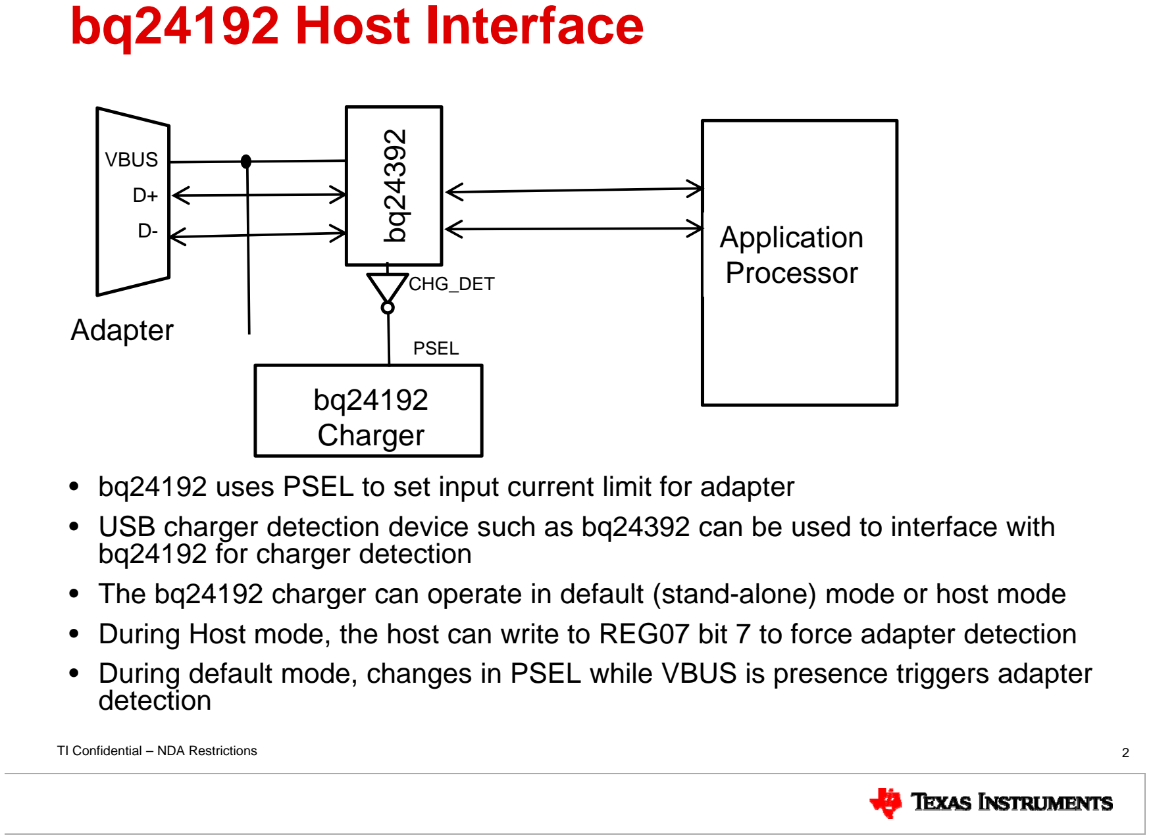
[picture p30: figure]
bq24192 Host Interface; VBUS; Application Processor; Adapter; CHG_DET; bq24192 Charger; PSEL; bq24192 for charger detection; detection; TI Confidential – NDA Restrictions

- bq24192 uses PSEL to set input current limit for adapter
- USB charger detection device such as bq24392 can be used to interface with
- The bq24192 charger can operate in default (stand- alone) mode or host mode
- During Host mode, the host can write to REG07 bit 7 to force adapter detection
- During default mode, changes in PSEL while VBUS is presence triggers adapter

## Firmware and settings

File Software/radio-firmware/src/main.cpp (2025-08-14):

#include "bq24190.h"
#include "pcf8575.h"
#include "pam8302a.h"
#include "sa868.h"
#include "ssd1306.h"

#define DEBUG_KEYPAD Serial
#define DEBUG_RSSI Serial

#define TASK_STACK_SIZE (4096)

#define SDA_PIN (1)
#define SCL_PIN (3)

#define PCF8575_INT_PIN (5)
pcf8575_config_t pcf8575;
#define ENCODER_CLK_PIN (PORT00)
#define ENCODER_DT_PIN (PORT01)
#define ENCODER_SW_PIN (PORT07)

#define PTT_BUTTON_PIN (PORT06) 


#define MAX_DISPLAY_COUNT 128
char display_buffer[MAX_DISPLAY_COUNT];
char *display_format_buffer;
ssd1306_config_t ssd1306;
TimerHandle_t displayTimer;

/* BQ24190 definitions */
#define BQ24190_INT_PIN (0)
// #define BQ24190_OTG_PIN
#define BQ24190_NCE_PIN (PORT03)
bq24190_config_t bq24190;
TimerHandle_t powerTimer;

// Table 16. REG09 Fault Register Description
const char* charger_faults_tag[4] {
  "Normal, ",
  "Input Fault (VBUS OVP or VBAT < VBUS < 3.8 V), ",
  "Thermal shutdown, ",
  "Charge Safety Timer Expiration, "
};
const char* ntc_faults_tag[5] {
  "Normal (T2-T3), ",
  "Warm (T3-T5), ",
  "Cool (T1-T2), ",
  "Cold (< T1), ",
  "Hot (> T5), "
};

int key_ghost_count;
int keys_entered;
int short_press_delay_milliseconds = 250;
int long_press_delay_milliseconds = 500;
TimerHandle_t inputTimer;

/* MAX98357A definitions */
// #define MAX98357A_BCLK (8)
// #define MAX98357A_LRCLK (9)
// #define MAX98357A_DIN (2)
// #define MAX98357A_SD (PORT04)
// max98357a_config_t max98357a;

#define PAM8302A_SD (PORT04)
pam8302a_config_t pam8302a;

/* SA868 definitions */
#define BAUD_RATE (9600)
#define RX_PIN (20)
#define TX_PIN (21)
#define SA868_PD_PIN (PORT05)
sa868_config_t sa868;
TimerHandle_t pttTimer;

volatile bool inputFlag = false;
void inputISR() {
  inputFlag = true;
}
// Rotary Encoder Increment Handling
volatile int rotary_encoder_clock = 0;
volatile int rotary_encoder_clocked = 0;
int rotary_encoder_counter = 0;
bool rotary_encoder_direction = false;
bool rotary_encoder_pressed = false;
bool rotary_encoder_ccw = false;
// Quadrature Encoding
void readEncoderDirection() {
  rotary_encoder_clock = pcf8575_readPort(ENCODER_CLK_PIN);
  if (rotary_encoder_clock != rotary_encoder_clocked
    && rotary_encoder_clock == 1) {
      if (pcf8575_readPort(ENCODER_DT_PIN) != rotary_encoder_clock) {
        rotary_encoder_counter--;
        rotary_encoder_ccw = true;
      } else {
        rotary_encoder_counter++;
        rotary_encoder_ccw = false;
      }
      Serial.printf("Rotary Encoder Incremented to (%d) %s\n",
        rotary_encoder_counter,
        rotary_encoder_ccw ? "CW" : "CCW");
  }
  rotary_encoder_clocked = rotary_encoder_clock;
}

// Push-To-Talk Button Handling
volatile bool ptt = false;
int pttElapsedSeconds = 0; // Elapsed PTT time in seconds
int pttTimeoutSeconds = 0; // Previous PTT time in seconds
// Software timer callback for counting PTT time in seconds 
void pttTimeoutCallback(TimerHandle_t xTimer) {
  pttElapsedSeconds++;
}
void activePTT() {
  pttTimeoutSeconds = pttElapsedSeconds;
  // Push-to-Talk has an optional timeout.
  if (sa868.PTT_TIMEOUT_SECONDS != -1 && pttTimeoutSeconds >= sa868.PTT_TIMEOUT_SECONDS) {
    //pcf8575_writePort(SA868_PTT_PIN, HIGH);  // Bypass PTT
    xTimerStop(pttTimer, 0);
    ptt = false;
    Serial.println("PTT Timeout reached, bypassing PTT...");
  }
}

// Potentiometer wiper is on ADC input pin.
#define VOLUME_WIPER_PIN 4

// const int frequency = 440; // frequency of square wave in Hz
// const int amplitude = 500; // amplitude of square wave
// const int sampleRate = 8000; // sample rate in Hz
// const int bps = 16;

// const int halfWavelength = (sampleRate / frequency); // half wavelength of square wave

// short sample = amplitude; // current sample value
// int count = 0;

//i2s_mode_t mode = I2S_PHILIPS_MODE; // I2S decoder is needed


void loop() {
  // Empty. Things are done in Tasks.
}

/*--------------------------------------------------*/
/*---------------------- Tasks ---------------------*/
/*--------------------------------------------------*/

// Received Signal Strength Indicator Handling
void updateRSSI() {
  int val = DMOERROR;
  // val = sa868_communication_handler(RSSI);
  if (val != DMOERROR) {
    // Datasheet suggests the module reports RSSI in dB.
    // What is the fixed reference value for the SA868?
    val += sa868.rssi_offset; // calibration offset for dBm
    //val *= -1; // RSSI is expected to be sub-milliwatt
    // -73 dBm is S9, -174 dBm S0
    sa868.rssi = -1*(255 - val);
    if (sa868.rssi != val) {
      sa868.rssi = val;
    }
  }
}

// Keypad Handling
char entry[8] = "";
bool rx_entry_mode = false, tx_entry_mode = false;

// TODO: make an alarm that indicates short or long keypresses.
void readKeypadEntry(char key) {
  if (key != '\0') {
    char key_to_enter[2];
    key_to_enter[0] = key;
    key_to_enter[1] = '\0';
    #ifdef DEBUG_KEYPAD
    DEBUG_KEYPAD.printf("Keypress to use: %s x%d\n", key_to_enter, key_ghost_count+1);
    #endif
    switch(key) {
      case('*'): // Use as RX Entry (7 chars)
        if (!rx_entry_mode && key_ghost_count == 2) {
          rx_entry_mode = true;
          strcpy(entry, "");
          Serial.printf("RX Entry Mode enabled...\n");
        }
        //vTaskDelay(long_press_delay_milliseconds);
        break;
      case('#'): // Use as TX Entry (7 chars)
        if (!tx_entry_mode && key_ghost_count == 2) {
          tx_entry_mode = true;
          strcpy(entry, "");
          Serial.printf("TX Entry Mode enabled...\n");
        }
        //vTaskDelay(long_press_delay_milliseconds);
        break;
      default:
        if ((rx_entry_mode || tx_entry_mode) && strlen(entry) < 7) {
          strcat(entry, key_to_enter);
          Serial.printf("Current Keypad Entry (%d): %s\n", strlen(entry), entry);
        }
        //vTaskDelay(short_press_delay_milliseconds);
        break;
    }
  }
  if (strlen(entry) >= 7) {
    Serial.printf("Leaving entry mode...\n");
    int val = updateFrequency(tx_entry_mode, entry);
    strcpy(entry, "");
    rx_entry_mode = false;
    tx_entry_mode = false;
  }
}

bool drawScreen = false;
void displayCallback(TimerHandle_t xTimer) {
  drawScreen = true;
}

const char* display_template[5] = {
  "%s RX: %.3d.%4.4d MHz\n",
  "%s TX: %.3d.%4.4d MHz\n",
  "%s ASQ: %d/8 VOL: %d/8\n",
  "%s CXCSS RX=%s\n%s CXCSS TX=%s\n"
};

char* display_format[5];

bool audio_squelch_entry_mode = false;

int8_t selection = 0;
uint16_t rotary_encoder_presses = 0;

void display_DMO_status() {
  display_format_buffer = (char *)pvPortMalloc(MAX_DISPLAY_COUNT);
  memset(display_format_buffer, 0, MAX_DISPLAY_COUNT);
  int offset = 0;
  display_format[0] = (char *)display_template[0];
  display_format[1] = (char *)display_template[1];
  display_format[2] = (char *)display_template[2];
  display_format[3] = (char *)display_template[3];
  selection = rotary_encoder_counter;
  if (rotary_encoder_pressed) {
    rotary_encoder_presses++;
    switch (selection) {
      // Change frequency
      case 0: {
        display_format[0] = (char *)"%s RX: XXX.XXXX MHz\n";
        rx_entry_mode = true;
        tx_entry_mode = false;
      };
      case 1: {
        display_format[1] = (char *)"%s TX: XXX.XXXX MHz\n";
        rx_entry_mode = false;
        tx_entry_mode = true;
      };
      // Change Audio Squelch Level
      case 2: {
        if (audio_squelch_entry_mode) { 
          selection = 2;
          sa868.squelch = rotary_encoder_counter;
          // if (rotary_encoder_presses >= 1 && sa868_communication_handler(SETGROUP) == 0) {
          //   audio_squelch_entry_mode = false;
          //   rotary_encoder_presses = 0;
          //   display_format[2] = (char *)"%s ASQ:  =%d VOL: %d/8\n";
          // }
        } else {
          display_format[2] = (char *)"%s ASQ: X/8 VOL: %d/8\n";
        }
        audio_squelch_entry_mode = true;
      };
      // Select Squelch System
      case 3: {
        display_format[3] = (char *)"%s CXCSS RX=XXXX\n%s CXCSS TX=%s\n";
      };
      case 4: {
        display_format[3] = (char *)"%s CXCSS RX=%s\n%s CXCSS TX=XXXX\n";
      };
    }
    rotary_encoder_pressed = false;
  }
  // carousel selection operation
  if (selection <= -1 ) {
    rotary_encoder_counter = 4;
  }
  if (selection > 4) {
    rotary_encoder_counter = 0;
  }
  offset += snprintf(display_format_buffer + offset, MAX_DISPLAY_COUNT - offset, display_format[0],
    (selection == 0) ? "*" : " ", sa868.rx_freq_mhz, sa868.rx_freq_khz
  );
  offset += snprintf(display_format_buffer + offset, MAX_DISPLAY_COUNT - offset, display_format[1],
    (selection == 1) ? "*" : " ", sa868.tx_freq_mhz, sa868.tx_freq_khz
  );
  if (ptt) {
      offset += snprintf(display_format_buffer + offset, MAX_DISPLAY_COUNT - offset,
        "  PTT: %d/180 sec \n", pttElapsedSeconds
      );
  } else {
      offset += snprintf(display_format_buffer + offset, MAX_DISPLAY_COUNT - offset,
        "  RSSI: %.3d dBm (%s)\n",
        sa868.rssi, sa868_s_meter()
      );
  }
  
  offset += snprintf(display_format_buffer + offset, MAX_DISPLAY_COUNT - offset,
    display_format[2], (selection == 2) ? "*" : " ",
    sa868.squelch, sa868.volume_level
  );

  offset += snprintf(display_format_buffer + offset, MAX_DISPLAY_COUNT - offset,
    display_format[3],
    (selection == 3) ? "*" : " ",
    sa868.rx_subaudio == "0000" ? "NONE" : sa868_ctcss_subtone(sa868.rx_subaudio),
    (selection == 4) ? "*" : " ",
    sa868.tx_subaudio == "0000" ? "NONE" : sa868_ctcss_subtone(sa868.tx_subaudio)
  );

  // Check if the final string fits in the display buffer
  if (offset >= MAX_DISPLAY_COUNT) {
      // Handle error: contents too long
      vPortFree(display_format_buffer);
      return;
  }
  snprintf(display_buffer, MAX_DISPLAY_COUNT, "%s", display_format_buffer);
  vPortFree(display_format_buffer);
}


void display_BMS_status() {
  display_format_buffer = (char *)pvPortMalloc(MAX_DISPLAY_COUNT);
  memset(display_format_buffer, 0, MAX_DISPLAY_COUNT);
  int offset = 0;

  if (bq24190.charger_fault == 0 /*Exclude Charger Fault: Normal*/) {
      offset += snprintf(display_format_buffer + offset, MAX_DISPLAY_COUNT - offset,
        "%s\n%s\n%s%s%s%s\n",
            bq24190.vbus_status,
            bq24190.charge_status,
            ((bq24190.system_status & DPM_STAT)   >> 3) ? "VINDPM or IINDPM, " : "Not DPM, ", //0
            ((bq24190.system_status & PG_STAT)    >> 2) ? "Power Good, " : "Not Power Good, ", //0
            ((bq24190.system_status & THERM_STAT) >> 1) ? "In Thermal Regulation, " : "Normal, ", //0
            ((bq24190.system_status & VSYS_STAT)      ) ? "In VSYSMIN Regulation (BAT < VSYSMIN)" : "Not in VSYSMIN Regulation (BAT > VSYSMIN)"
      );
  } else {
      offset += snprintf(display_format_buffer + offset, MAX_DISPLAY_COUNT - offset,
        "Power Faults: %s%s%s%s%s%s", // Enumerate each fault as presented
            ((bq24190.fault_status & WATCHDOG_FAULT) >> 7) ? "WATCHDOG, " : "",
            ((bq24190.fault_status & BOOST_FAULT)    >> 6) ? "BOOST, " : "",
            (bq24190.charger_fault) >= 0                        ? charger_faults_tag[bq24190.charger_fault] : "",
            ((bq24190.fault_status & BAT_FAULT)      >> 3) ? "BATTERY OVP, " : "",
            (bq24190.ntc_fault) >= 0                            ? ntc_faults_tag[bq24190.ntc_fault] : "",
            ((bq24190.fault_status)                 ) == 0 ? "NONE; " : ""
      );
  }
  // Check if the final string fits in the display buffer
  if (offset >= MAX_DISPLAY_COUNT) {
      // Handle error: contents too long
      vPortFree(display_format_buffer);
      return;
  }
  snprintf(display_buffer, MAX_DISPLAY_COUNT, "%s", display_format_buffer);
  vPortFree(display_format_buffer);
}

// #include <I2S.h>
// const int frequency = 440; // frequency of square wave in Hz
// const int amplitude = 500; // amplitude of square wave
// const int sampleRate = 8000; // sample rate in Hz
// const int bps = 16;

// const int halfWavelength = (sampleRate / frequency); // half wavelength of square wave

// short sample = amplitude; // current sample value
// int count = 0;

// i2s_mode_t mode = I2S_PHILIPS_MODE; // I2S decoder is needed

// Volume Level Control Handling
bool updateVolume() {
  int response;
  uint16_t wiper = analogRead(VOLUME_WIPER_PIN);
  uint8_t volume = map(wiper, 0, 4095, 1, 8);
  // analogReadResolution(12);
  if (sa868.volume_level != volume) {
    sa868.volume_level = volume;
    // int response = sa868_communication_handler(SETVOLUME);
  }
  return response;
}
void audioCallback(TimerHandle_t xTimer) {
  // //uint16_t sampled_audio = analogRead(SA868_AF_PIN);
  // if (count % halfWavelength == 0) {
  //     // invert the sample every half wavelength count multiple to generate square wave
  //     sampled_audio = edge ? INT16_MAX : INT16_MIN;
  // }
  // count++;
  // //Serial.printf("SA868_AF_PIN: %d (centered %d)", sampled_audio, sampled_audio - 512);
  // max98357a_audio_data_in(sampled_audio);
}

volatile bool booted = false;
volatile bool debug_mode = false; 
static void task(void *arg) {
  int val;
  while (1) {
    // Flag for change on Port Expander 
    if (inputFlag) {
      // Poll PTT button from port expander.
      ptt = (pcf8575_readPort(PTT_BUTTON_PIN) == LOW);
      // Poll Rotary Encoder from port expander.
      readEncoderDirection();
      rotary_encoder_pressed = (pcf8575_readPort(ENCODER_SW_PIN) == LOW);
      if (!booted && rotary_encoder_pressed) {
        debug_mode = true;
      }
      // Poll keypad from port expander.
      char key = pcf8575_readKeypad(key_ghost_count);
      readKeypadEntry(key);
    }
    booted = true;
    if (ptt) {
      if (!xTimerIsTimerActive(pttTimer)) {
        xTimerStart(pttTimer, 0);
      }
      activePTT();
    } else {
      // once no longer PTT, stop timeout timer and start audio.
      if (xTimerIsTimerActive(pttTimer)) {
        xTimerStop(pttTimer, 0);
        pttTimeoutSeconds = 0;
        pttElapsedSeconds = 0;
      }
    }
    if (!xTimerIsTimerActive(displayTimer)) {
      xTimerStart(displayTimer, 0);
    }
    if (drawScreen) {
      bq24190_maintainHostMode();
      if (debug_mode) {
        bq24190_enableCharging(false);
        display_BMS_status();
      } else {
        updateVolume();
        // updateRSSI();
        display_DMO_status();
      }
      ssd1306_drawScreen(display_buffer);
      drawScreen = false;
    }
  }
  vTaskDelete(NULL);
}

void setup() {
  Serial.begin(115200);
  // Serial.println("I2S simple tone");
  //I2S.setAllPins(MAX98357A_BCLK, MAX98357A_LRCLK, MAX98357A_DIN, 26); // (CLK, WS, IN, OUT)
  // start I2S at the sample rate with 16-bits per sample
  // if (!I2S.begin(mode, sampleRate, bps)) {
  //   Serial.println("Failed to initialize I2S!");
  //   while (1); // do nothing
  // }

  Wire.setPins(SDA_PIN, SCL_PIN);
  Wire.begin();

  pinMode(VOLUME_WIPER_PIN, INPUT);
  
  // Initialize GPIO expander
  pcf8575.pin_interrupt = PCF8575_INT_PIN;
  attachInterrupt(digitalPinToInterrupt(pcf8575.pin_interrupt), inputISR, CHANGE);
  pcf8575.i2c = &Wire;
  int val = pcf8575_init(pcf8575);
  pcf8575_portMode(ENCODER_CLK_PIN, INPUT_PULLUP);
  pcf8575_portMode(ENCODER_DT_PIN, INPUT_PULLUP);
  pcf8575_portMode(ENCODER_SW_PIN, INPUT_PULLUP);
  rotary_encoder_clocked = pcf8575_readPort(ENCODER_CLK_PIN); // initial quadrature
  // Initialize Keypad GPIO pins
  pcf8575_portMode(PORT10, INPUT_PULLUP);
  pcf8575_portMode(PORT11, INPUT_PULLUP);
  pcf8575_portMode(PORT12, INPUT_PULLUP);
  pcf8575_portMode(PORT13, INPUT_PULLUP);
  pcf8575_portMode(PORT14, OUTPUT);
  pcf8575_portMode(PORT15, OUTPUT);
  pcf8575_portMode(PORT16, OUTPUT);
  pcf8575_portMode(PORT17, OUTPUT);

  // Initialize OLED display
  ssd1306.i2c = &Wire;
  snprintf(display_buffer, MAX_DISPLAY_COUNT, "%s", "UHF Handheld Radio\nBased on SA8X8 Module\nde Eric Mutton KJ5DIF\nThanks to UTD ECE\n& Dr. Bill Swartz");
  do {
    val = ssd1306_init(ssd1306);
    ssd1306_drawScreen(display_buffer);
    vTaskDelay(1000/portTICK_PERIOD_MS);
  } while (val == -1);
  // Initialize power subsystem
  bq24190.OTG = true;
  bq24190.pin_interrupt = BQ24190_INT_PIN;
  pinMode(bq24190.pin_interrupt, INPUT_PULLUP);
  // pcf8575_portMode(BQ24190_OTG_PIN, OUTPUT); // active high
  // pcf8575_writePort(BQ24190_OTG_PIN, bq24190.OTG);
  pcf8575_portMode(BQ24190_NCE_PIN, OUTPUT); // active low
  pcf8575_writePort(BQ24190_NCE_PIN, LOW);
  bq24190.i2c = &Wire;
  val = bq24190_init(bq24190);
  // enable charging in host mode
  bq24190_enableCharging(false);

  // Initialize audio subsystem
  // i2s_pin_config_t pin_config = {
  //   .bck_io_num = MAX98357A_BCLK,   // Serial clock (SCK), aka bit clock (BCK)
  //   .ws_io_num = MAX98357A_LRCLK,   // Word select (WS), i.e. command (channel) select, used to switch between left and right channel data
  //   .data_out_num = MAX98357A_DIN,   // Serial data signal (SD), used to transmit audio data in two's complement format
  //   .data_in_num = I2S_PIN_NO_CHANGE  // Not used
  // };
  // max98357a.pin_config = pin_config;
  // max98357a.pin_shutdown = MAX98357A_SD;
  // pcf8575_portMode(max98357a.pin_shutdown, OUTPUT);
  // pcf8575_writePort(max98357a.pin_shutdown, LOW); // active high
  // val = max98357a_init(max98357a);
  pam8302a.pin_shutdown = PAM8302A_SD;
  pcf8575_portMode(pam8302a.pin_shutdown, OUTPUT);
  pcf8575_writePort(pam8302a.pin_shutdown, LOW); // active high
  val = pam8302a_init(pam8302a);
  // audioTimer = timerBegin(0, 80, true); // Timer 0, prescaler 80 (1 MHz)
  // timerAttachInterrupt(audioTimer, &audioCallback, true);
  //timerAlarmWrite(audioTimer, 12500, true); // 1 second
  //timerAlarmEnable(audioTimer); // Start the timer

  // Initialize communications subsystem 
  sa868.pin_shutdown = SA868_PD_PIN;
  pcf8575_portMode(sa868.pin_shutdown, OUTPUT); 
  pcf8575_writePort(sa868.pin_shutdown, LOW); // active low
  pcf8575_portMode(PTT_BUTTON_PIN, INPUT_PULLUP); // active low
  /**
   * UART Interface Format:
   * Baud rate = 9600 Baud
   * Data bit = 8 bit
   * Parity = None
   * Stop bit = 1 bit
   * Terminal Rx,Tx pins = GPIO20,GPIO21 @ 3.3V
   */
  Serial1.begin(BAUD_RATE, SERIAL_8N1, RX_PIN, TX_PIN);
  sa868.UART = &Serial0; // using UART0 for SA868
  // sa868.MAX_CONNECTION_ATTEMPTS = 3;
  sa868.PTT_TIMEOUT_SECONDS = 180; // 180 second timeout
  sa868.bandwidth_wide_fm = 1; // BW = 25 kHz
  sa868.squelch = 3;
  sa868.volume_level = 3;

  // int repeater_offset = 5; // +5 MHz
  // sa868.rx_subaudio = "0015"; // CTCSS = 110.9 Hz
  // sa868.rx_freq_mhz = 443; 
  // sa868.rx_freq_khz = 3750;
  // sa868.tx_freq_mhz = sa868.rx_freq_mhz + repeater_offset; // 448 
  // sa868.tx_freq_khz = 3750; 

  // national calling frequency 446.0000 MHz
  sa868.rx_freq_mhz = 446;
  sa868.rx_freq_khz = 0000;
  sa868.tx_freq_mhz = 446;
  sa868.tx_freq_khz = 0000;
  // dBm = dBW - (30 dBm - 16 dBm)
  //sa868.rssi_offset = 99;
  
  // val == DMOERROR;
  // do {
  //   val = sa868_init(sa868);
  //   vTaskDelay(1000/portTICK_PERIOD_MS);
  // } while (val == DMOERROR);

  // Display Refresh Timer
  displayTimer = xTimerCreate("DisplayTimer", pdMS_TO_TICKS(1000), pdFALSE, NULL, displayCallback);
  // PTT Timeout Timer
  pttTimer = xTimerCreate("PTTTimer", pdMS_TO_TICKS(1000), pdFALSE, NULL, pttTimeoutCallback);

  xTaskCreate(task, "main_task", TASK_STACK_SIZE, NULL, 10, NULL);
}

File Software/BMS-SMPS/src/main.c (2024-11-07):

#include "zephyr/sys/printk.h"
#include <zephyr/kernel.h>
#include <zephyr/device.h>
#include <zephyr/devicetree.h>
#include <zephyr/drivers/charger.h>
#include <zephyr/drivers/uart.h>
#include <zephyr/logging/log.h>
#include <sys/errno.h>
#include <ctype.h>


LOG_MODULE_REGISTER(nicerf_sa868);

static const struct device *chgdev = DEVICE_DT_GET(DT_NODELABEL(charger));
// static const struct device *trxdev = DEVICE_DT_GET(DT_NODELABEL(transceiver));

// for now, just use the zephyr shell UART.
#define UART_DEVICE_NODE DT_CHOSEN(zephyr_shell_uart)
static const struct device *uartdev = DEVICE_DT_GET(UART_DEVICE_NODE);

char sa868_ctdss_code[100][4] = {
	"023I", "025I", "026I", "031I", "032I", "043I", "047I", "051I", "054I", "065I", 
	"071I", "072I", "073I", "074I", "114I", "115I", "116I", "125I", "131I", "132I", 
	"134I", "143I", "152I", "155I", "156I", "162I", "165I", "172I", "174I", "205I",
	"223I", "226I", "243I", "244I", "245I", "251I", "261I", "263I", "265I", "271I",
	"306I", "311I", "315I", "331I", "343I", "346I", "351I", "364I", "365I", "371I", 
	"411I", "412I", "413I", "423I", "431I", "432I", "445I", "464I", "465I", "466I",
	"503I", "506I", "516I", "532I", "546I", "565I", "606I", "612I", "624I", "627I", 
	"631I", "632I", "654I", "662I", "664I", "703I", "712I", "723I", "731I", "732I", 
	"734I", "743I", "754I"
};

uint32_t sa868_ctdss_pattern[100] = {
	0x640E37, 0x540F6B, 0x340DD3, 0x4C0FC5, 0x2C0D7D, 0x620B6D, 0x720DF8, 0x4A0A9F,
	0x1A097B, 0x560C5D, 0x4E0CF3, 0x2E0E4B, 0x6E0B3A, 0x1E0F17, 0x190BD6, 0x590EA7, 
	0x390C1F, 0x550EF0, 0x4D0E5E, 0x2D0CE6, 0x1D0DBA, 0x630AF6, 0x2B09BC, 0x5B0D91, 
	0x3B0F29, 0x2709EB, 0x570DC6, 0x2F0FD0, 0x1F0E8C, 0x508CBB, 0x648B8B, 0x34886F, 
	0x628ED1, 0x128AFC, 0x528F8D, 0x4A8F23, 0x468F74, 0x6688BD, 0x5689E1, 0x4E894F, 
	0x318F98, 0x498D8E, 0x598B1B, 0x4D8BE2, 0x638F4A, 0x338CAE, 0x4B8EB8, 0x178D0B, 
	0x57887A, 0x4F88D4, 0x484B77, 0x2849CF, 0x684CBE, 0x644CE9, 0x4C4D1B, 0x2C4FA3, 
	0x5248EF, 0x164BF2, 0x564E83, 0x364C3B, 0x614B1E, 0x3148FA, 0x394EC1, 0x2D4E38, 
	0x334BCC, 0x574F18, 0x30CCDD, 0x28CC73, 0x14CD78, 0x74CFC0, 0x4CC8A7, 0x2CCA1F, 
	0x1ACE19, 0x26CF12, 0x16CE4E, 0x61CEA2, 0x29CDE8, 0x65C8CE, 0x4DC93C, 0x2DCB84, 
	0x1DCAD8, 0x63CD94, 0x1BCF82
};

/* 
* CONNECT: Detect the module is in normal working status.
* SWEEP: Set the frequency to scan
* SETGROUP: Set the working parameters of the module
* SETVOLUME: Set the volume level of the module
* RSSI: Read Received Signal Strength Indicator value of the module
*/
enum instruction_set {
	CONNECT = 0, // AT+DMOCONNECT
	SWEEP, // S+SWEEP=?
	SETGROUP, // AT+DMOSETGROUP=?
	SETVOLUME, // AT+DMOSETVOLUME=?
	RSSI, // AT+RSSI?
	SETFILTER // AT+SETFILTER=?
};

#define MSG_SIZE 50
/* queue to store up to 10 messages (aligned to 4-byte boundary) */
K_MSGQ_DEFINE(uart_msgq, MSG_SIZE, 10, 4);

/* receive buffer used in UART ISR callback */
static char rx_buf[MSG_SIZE];
static int rx_buf_pos;
/*
 * Read characters from UART until line end is detected. Afterwards push the
 * data to the message queue.
 */
void serial_cb(const struct device *dev, void *user_data)
{
	uint8_t c;

	if (!uart_irq_update(uartdev)) {
		return;
	}

	if (!uart_irq_rx_ready(uartdev)) {
		return;
	}

	/* read until FIFO empty */
	while (uart_fifo_read(uartdev, &c, 1) == 1) {
		if ((c == '\n' || c == '\r') && rx_buf_pos > 0) {
			/* terminate string */
			rx_buf[rx_buf_pos] = '\0';

			/* if queue is full, message is silently dropped */
			k_msgq_put(&uart_msgq, &rx_buf, K_NO_WAIT);

			/* reset the buffer (it was copied to the msgq) */
			rx_buf_pos = 0;
		} else if (rx_buf_pos < (sizeof(rx_buf) - 1)) {
			rx_buf[rx_buf_pos++] = c;
		}
		/* else: characters beyond buffer size are dropped */
	}
}

int read_in_response(enum instruction_set instruction, char *response) {
	int val = -1; // command response value begins invalid
	switch(instruction) {
		case(CONNECT):
			// +DMOCONNECT:0 -> Normal working status
			sscanf(response, "+DMOCONNECT:%d\r\n", &val);
			break;
		case(SWEEP):
			// S=0 -> The frequency to be scanned has a signal
			// S=1 -> There is no signal to sweep the frequency
			sscanf(response, "S=%d\r\n", &val);
			break;
		case(SETGROUP):
			// +DMOSETGROUP:0 -> Successfully set working parameters
			// +DMOSETGROUP:1 -> Data setting is out of range
			sscanf(response, "+DMOSETGROUP:%d\r\n", &val);
			break;
		case(SETVOLUME):
			// +DMOSETVOLUME:0 -> Successfully set volume level
			// +DMOSETVOLUME:1 -> Failed volume level setup
			sscanf(response, "+DMOSETVOLUME:%d\r\n", &val);
			break;
		case(RSSI):
			// RSSI:0bXXX -> Current signal strength value
			sscanf(response, "RSSI:%3d", &val);
			break;
		case(SETFILTER):
			// +DMOSETFILTER:0 -> Successfully set module filter
			// +DMOSETFILTER:1 -> Failed filter setup 
			sscanf(response, "+DMOSETFILTER:%d\r\n", &val);
			break;
	}
	return val;
}

/*
 * Print a null-terminated string character by character to the UART interface
 */
void print_uart(char *buf)
{
	int msg_len = strlen(buf);

	for (int i = 0; i < msg_len; i++) {
		uart_poll_out(uartdev, buf[i]);
	}
}

int main(void)
{
	/*
	 * Texas Instruments BQ24190 initialization
	 */
	if (chgdev == NULL) {
		printk("Error: no charger device found.\n");
		return 0;
	}

	if (!device_is_ready(chgdev)) {
		printk("Error: Device \"%s\" is not ready; "
		       "check the driver initialization logs for errors.\n",
		       chgdev->name);
		return 0;
	}

	/*
	 * NiceRF SA868 initialization
	 */
	// https://github.com/zephyrproject-rtos/zephyr/blob/main/samples/drivers/uart/echo_bot/src/main.c

	if (!device_is_ready(uartdev)) {
		printk("Error: Device \"%s\" is not ready; "
		       "check the driver initialization logs for errors.\n",
		       uartdev->name);
    	return 0;
	}

	/* configure interrupt and callback to receive data */
	int ret = uart_irq_callback_user_data_set(uartdev, serial_cb, NULL);
	
	if (ret < 0) {
		if (ret == -ENOTSUP) {
			printk("Interrupt-driven UART API support not enabled\n");
		} else if (ret == -ENOSYS) {
			printk("UART device does not support interrupt-driven API\n");
		} else {
			printk("Error setting UART callback: %d\n", ret);
		}
		return 0;
	}
	uart_irq_rx_enable(uartdev);

	/* send data over the UART*/

	//char queuedCommand[50] = "AT+DMOSETGROUP=0,415.1250,415.1250,0012,4,0013\r\n";

	char queuedCommand[17] = "AT+DMOCONNECT\r\n";

	print_uart(queuedCommand);

	// wait for response
	char response[MSG_SIZE];
	while (k_msgq_get(&uart_msgq, &response, K_FOREVER) == 0);

	// read in the response command value

	enum instruction_set instruction = CONNECT;

	int result = read_in_response(instruction, response);

	printk("Response from SA868: %d", result);
	return 0;
}

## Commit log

2024-08-22 feat: include first draft of SA868 breakout board
    [sa8x8-breakout.kicad_pcb, sa8x8-breakout.kicad_sch, sa8x8-breakout.step]
2024-08-29 chore: add .gitignore for KiCAD local files
2024-08-29 fix: use templated GitHub KiCad.gitignore
2024-08-29 chore: move KiCAD files into dedicated directory
    [sa8x8-breakout-B_Cu.gbr, sa8x8-breakout-B_Mask.gbr, sa8x8-breakout-B_Paste.gbr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]
2024-08-29 feat: include first draft of BMS-SMPS testbench board
    [bms-smps-testbench.kicad_pcb, bms-smps-testbench.kicad_sch]
2024-09-01 fix: consider removing module pads overlay on flexypin footprint
    [sa8x8-breakout-old.kicad_pcb]
2024-09-19 feat: include interactive bom
2024-10-15 fix: bring sa8x8 flexypins closer, add smps resistor
    [bms-smps-testbench.kicad_sch, sa8x8-breakout.kicad_pcb]
2024-10-19 fix: enter charge type 3 from VBUS terminal
    [main.c]
2024-10-19 feat: re-add status update for sample switch
2024-11-07 fix: reduce max charge voltage
2024-11-07 feat: begin UART configuration
2024-11-07 feat: begin SA868 communication from UART sample
2024-11-14 feat: working FreeRTOS proof-of-concept Arduino sketch
2024-11-15 feat: begin implementing module power down
2024-11-15 feat: separate sa868 sources from Arduino sketch
2024-11-15 docs: move BMS-SMPS guide, begin charge handler discussion
2024-11-15 docs: begin UART FIFO discussion
2024-11-29 refactor: extern device config and pass interface instance by reference
2024-11-29 feat: working bq24190 driver for host mode
2024-12-04 feat: respect OTG charger conf
2024-12-04 refactor: fold dmo debug into driver
2024-12-04 feat: move all low speed IO to PCF refactor: move more keypad to dedicated handling refactor: use FreeRTOS Timer Handling for PTT
2024-12-16 fix: reduce PCF port updates during scan
    [pcf8575.cpp]
2024-12-16 feat: Attach pcf interrupt, begin i2s, new timer-based polls
2024-12-16 fix: adhere to board tree
2024-12-16 feat: begin i2s audio amp driver
2024-12-16 feat: begin main hardware symbol and footprint libraries
2024-12-16 feat: begin broad subsystem schematic capture
    [audio_subsystem.kicad_sch, computing_subsystem.kicad_sch, display.kicad_sch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]
2024-12-16 chore: reflect latest breakout file, no notable changes
    [sa8x8-breakout.kicad_pcb]
2024-12-16 feat: plot current hardware schematic capture
2024-12-18 feat: add stat & pg indicators, psel solder jumper, begin power switch
    [power_subsystem.kicad_sch]
2024-12-18 feat: configuration for audio amp through solder jumpers with set defaults
    [audio_subsystem.kicad_sch]
2024-12-18 chore: clean up box graphics
    [spur-demo.kicad_sch]
2024-12-18 feat: plot power and audio changes
2024-12-18 fix: set JP6 to use audio amp as mono
    [audio_subsystem.kicad_sch, power_subsystem.kicad_sch]
2024-12-18 feat: add behavior select solder jumpers: default 3-wire SPI
    [display.kicad_sch]
2024-12-18 fix: reflect accurate JPX configurations given 1+2 default jump
    [display.kicad_sch]
2024-12-18 fix: give mic level setpoint potentiometer a name
    [audio_subsystem.kicad_sch]
2024-12-18 feat: begin footprint assignment, unify +3.3V PWRREFs
    [audio_subsystem.kicad_sch, computing_subsystem.kicad_sch, display.kicad_sch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]
2024-12-19 fix: minify footprint library use and resolve 3d models
2024-12-19 fix: remove node breaking col1 and row4 net resolution
    [keypad.kicad_sch]
2024-12-19 feat: assign solder jumper footprints, begin testpoints
    [audio_subsystem.kicad_sch, display.kicad_sch, power_subsystem.kicad_sch]
2024-12-19 feat: use smaller 1N5819 diode footprint 0603 imperial
    [spur-demo.kicad_sch]
2024-12-19 chore: replot hardware schematic
2024-12-20 docs: add application note for keypad scanning
    [keypad.kicad_sch]
2024-12-20 chore: ignore eschema and pcbnew lock files
2024-12-20 fix: geographically reannotate keypad DTMF matrix
    [keypad.kicad_sch]
2024-12-22 feat: add solder jumper for usb current limit select
    [spur-demo.kicad_sch]
2024-12-25 feat: establish microphone module footprint and header
    [audio_subsystem.kicad_sch]
2024-12-25 chore: name boot and reset push buttons
    [computing_subsystem.kicad_sch]
2024-12-25 chore: begin DRC footprint exclusions for USB and VSSOP clearance
2024-12-25 feat: phase out screw terminals in favor of real connectors
    [power_subsystem.kicad_sch]
2025-03-06 feat: squash recaptured schematics and footprint reassignments
    [audio_subsystem.kicad_sch, computing_subsystem.kicad_sch, display.kicad_sch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]
2025-03-06 docs: Add reference microphone module schematic, begin modulation
2025-03-06 chore: replot hardware schematic, regenerate interactive BOM
2025-04-22 chore: refresh to KiCAD version 9.0
    [audio_subsystem.kicad_sch, computing_subsystem.kicad_sch, display.kicad_sch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]
2025-05-08 feat: include draft PC Board
    [spur-demo-card.kicad_pcb, spur-demo-without-display.kicad_pcb, spur-demo.kicad_pcb]
2025-05-11 chore: plot schematic and update to KiCAD 9.0, export 3D image
    [bms-smps-testbench.kicad_pcb, bms-smps-testbench.kicad_sch]
2025-05-19 feat: completely reroute demo PCB, zones still not fully connected
    [power_subsystem.kicad_sch, spur-demo.kicad_pcb]
2025-05-19 chore: replot demo schematic
2025-05-24 fix: begin clarifying internal CXCSS code lookups
    [main.cpp, sa868.cpp]
2025-05-26 feat: finish DRC of demo PCB and remove islanding
    [spur-demo.kicad_pcb]
2025-05-26 fix: correct KiCAD project footprint library
2025-05-26 chore: save DRC report exclusions for ESP32 DevKit
2025-05-31 chore: revise readme to include a BMS layout example
2025-05-31 fix: resolve liunk to image asset for BMS layout
2025-06-14 fix: minimize UART buffer vTaskDelay use to init instructions, refactor debug printing, zero rssi offset
    [sa868.cpp]
2025-06-14 fix: ensure blocking DMO init, simplify RSSI callback
    [main.cpp]
2025-06-14 fix: simplify PTT callback, clarify use of polling
    [main.cpp]
2025-06-14 feat: begin rotary encoder implementation, refine volume leveling, swap PTT bypass PORT07 with rotary switch
    [main.cpp]
2025-06-14 fix: remove use of duplicate DMO config
    [main.cpp]
2025-06-14 feat: reduce software timer use, begin settings navigation
2025-06-17 feat: add rotary encoder to demo board
    [spur-demo.kicad_pcb, spur-demo.kicad_sch]
2025-06-17 chore: specify encoder footprint, replot demo schematic
    [spur-demo.kicad_pcb, spur-demo.kicad_sch]
2025-06-17 chore: clarify confused use of PORT07 in prototype firmware and COL5 for switch matrix
    [spur-demo.kicad_sch]
2025-06-18 fix: disconnect unused COL5 of switch matrix in favor of encoder switch
    [spur-demo.kicad_pcb, spur-demo.kicad_sch]
2025-07-31 fix: remove OTG bq24193 pin from GPIO MUX
    [main.cpp]
2025-07-31 fix: rotate keypad layout for demo PC Board use
    [pcf8575.cpp]
2025-08-02 fix: swap 3V3 and GND for SSD1306 Module
    [spur-demo.kicad_pcb, spur-demo.kicad_sch]
2025-08-13 feat: begin simple shutdown pin driver for pam8302
2025-08-14 fix: select correct standoff size in schematic
    [keypad.kicad_sch]
2025-08-14 chore: correctly mark pin shutdown as active low
2025-08-14 feat: include pin shutdown for module
2025-08-14 feat: swap audio modules, reassign GPIO, begin debug and boot menus, add USB CDC on Boot and USB Mode 1 build flags
    [main.cpp]
2025-09-25 fix: correct pulldown resistor values from values used in pullup configuration
    [spur-demo.kicad_sch]
2025-09-25 fix: correct NTC thermistor resistor network
    [power_subsystem.kicad_sch]
2025-10-01 fix: update PCB to reflect corrected NTC network, reroute
    [spur-demo.kicad_pcb, spur-demo.kicad_sch]
